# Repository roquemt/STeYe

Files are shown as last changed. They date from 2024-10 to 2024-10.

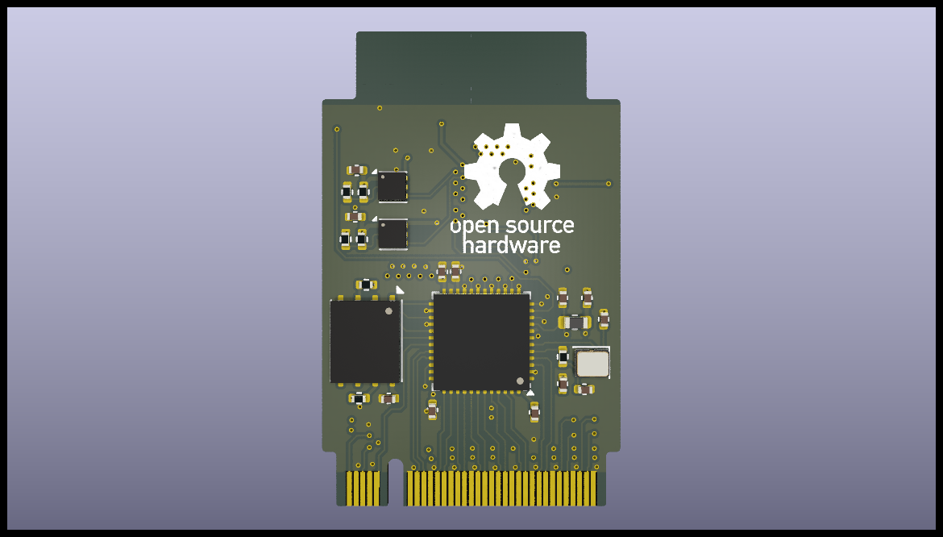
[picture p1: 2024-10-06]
STeYe M.2 Board/Renders/Bottom view.png

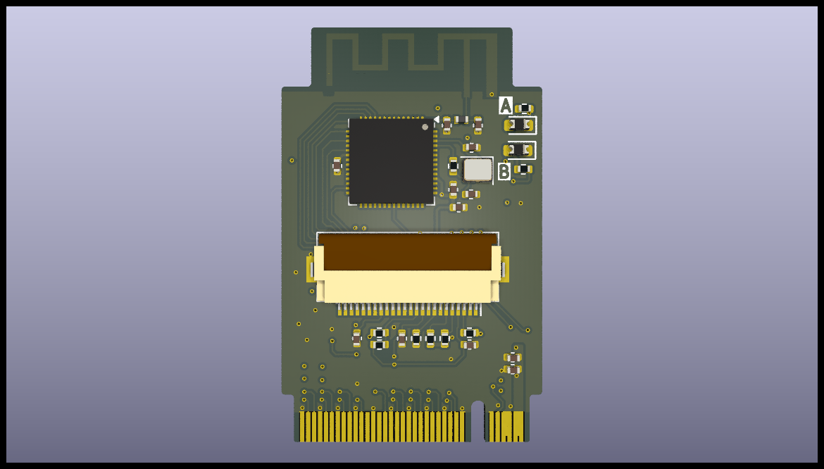
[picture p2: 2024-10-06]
STeYe M.2 Board/Renders/Top View.png

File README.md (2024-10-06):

# STeYe
Flight computer for rocket competition. 

This flight computer is designed for high-performance rocketry competitions, offering precise measurement and control for various flight parameters. The system integrates a range of sensors and features to ensure reliable data acquisition and communication throughout the flight. It is built with flexibility, durability, and scalability in mind for a variety of mission profiles.

Key Features:

-  Accelerometers: Dual-range accelerometers (+/-16g and +/-200g) for accurate low and high-g-force measurement during flight.
-  Pressure Sensor: Atmospheric pressure monitoring for altitude and environmental data.
-  Humidity & Temperature Sensor: Measures environmental conditions critical for flight analysis.
-  Magnetometer: Provides orientation and heading information by sensing the Earth’s magnetic field.
-  Current Sensor: Tracks power consumption for optimized energy management.
-  Camera Interface (FPC): Supports OV5640 camera for video and image capture during flight.
-  WiFi & Bluetooth: Wireless communication for data transfer and real-time telemetry.
-  GNSS (Global Navigation Satellite System): Provides accurate positioning data for tracking and flight path monitoring.
-  LoRa: Long-range, low-power communication capability for telemetry.
-  Pyro Channel: Single pyro channel for controlled deployment of parachutes or other pyrotechnic devices.
-  Motor Control: Supports either one dual-coil stepper motor or up to four servomotors, operating between 5V and 12V for mechanical actuation.
-  Passive Buzzer: Provides audio alerts for critical status or events.
-  LED Indicators: Visual feedback for power, status, and activity.
-  Memory: Includes both flash storage and microSD for data logging and flight data retention.

Carrier Board (sensors and peripherals)
Top view
Bottom view

M.2 Board (Microcontrollers and Wifi)
Top View
Bottom view

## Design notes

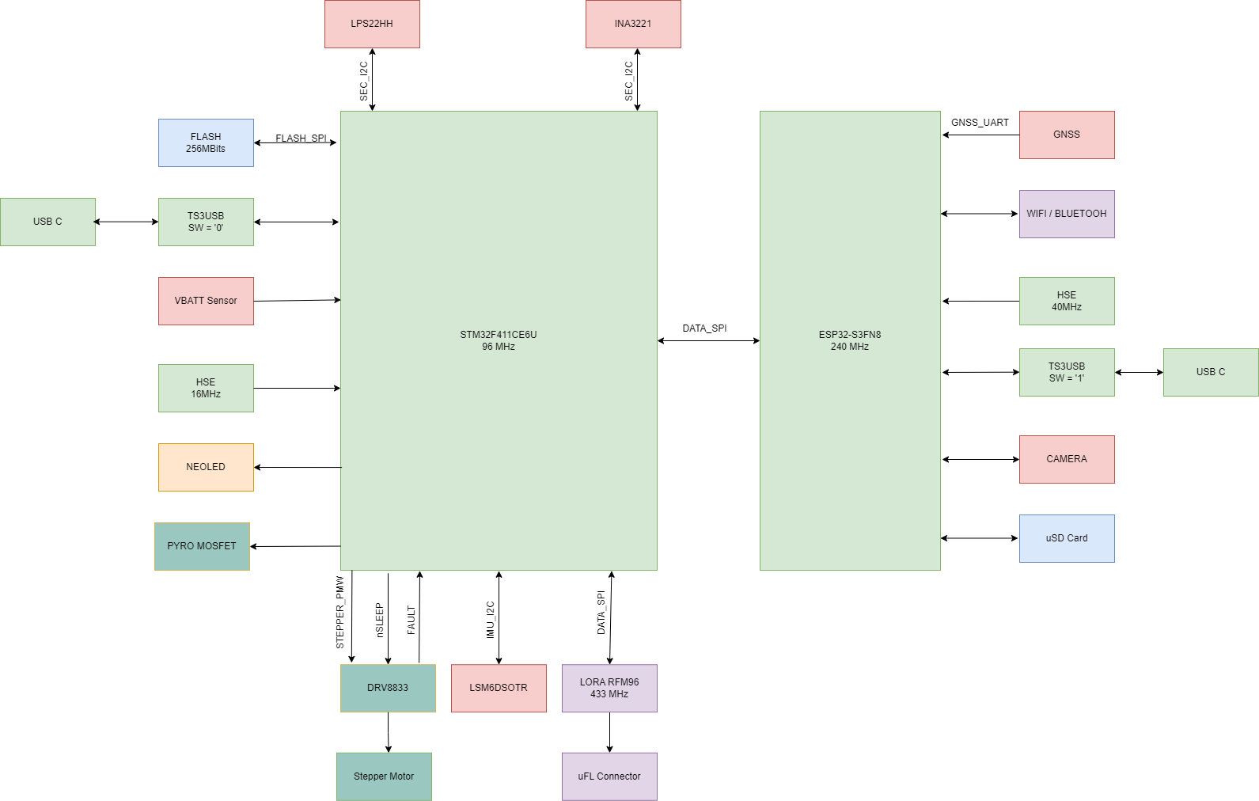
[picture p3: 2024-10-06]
Block Diagram.png

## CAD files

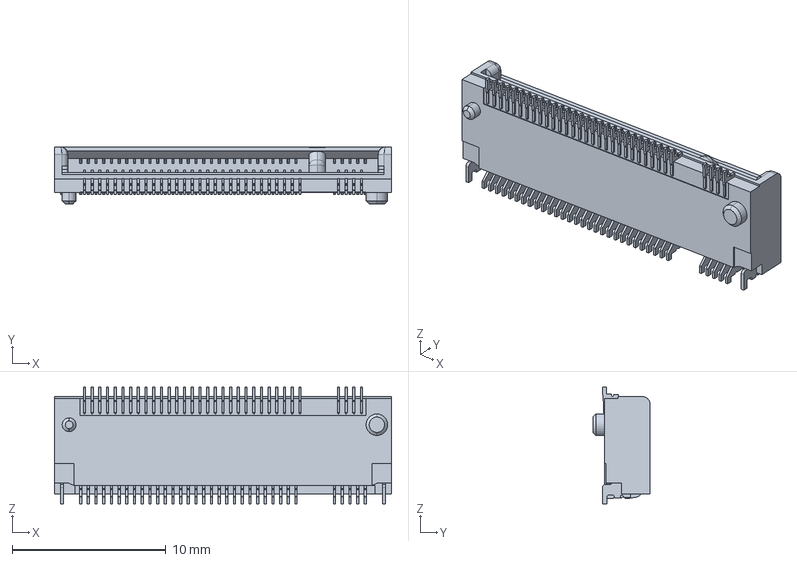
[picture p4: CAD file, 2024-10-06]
SteYe Carrier Board/3D models/sm3zs067u310amr1200.stp
21.9 x 3.72 x 7.60 mm

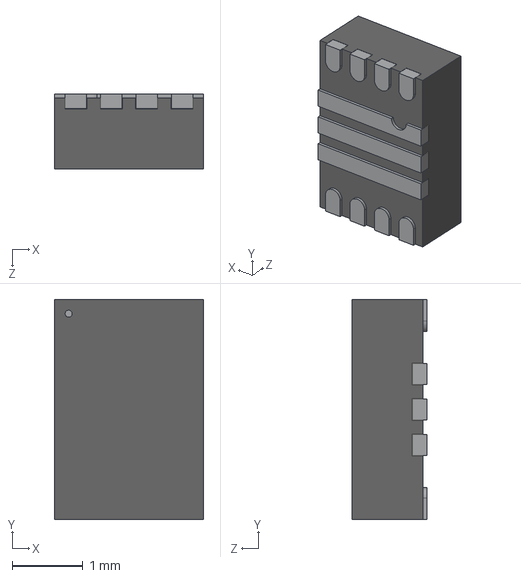
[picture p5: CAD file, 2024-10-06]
SteYe Carrier Board/3D models/User Library-Tps 62135.STEP
2.10 x 3.10 x 1.05 mm

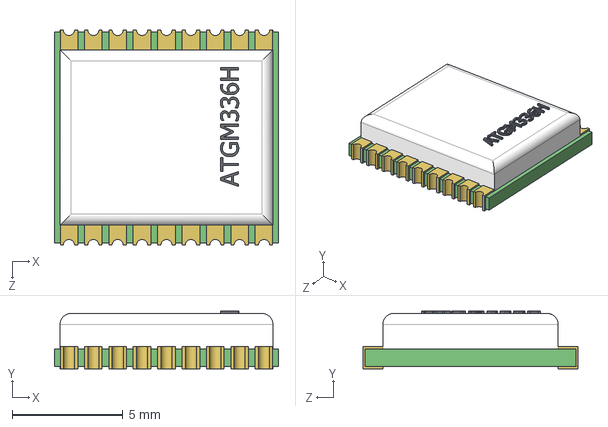
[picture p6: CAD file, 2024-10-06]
SteYe Carrier Board/3D models/User Library-ATGM336H.STEP
10.1 x 2.60 x 9.70 mm

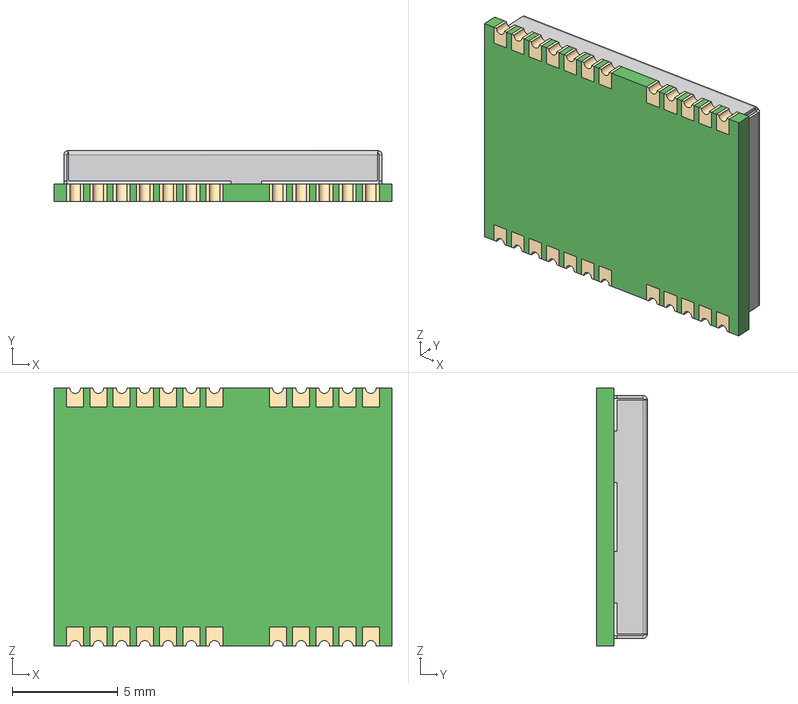
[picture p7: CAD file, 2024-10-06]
SteYe Carrier Board/3D models/U Blok NEO-6M-0-001.step
16.0 x 2.40 x 12.2 mm

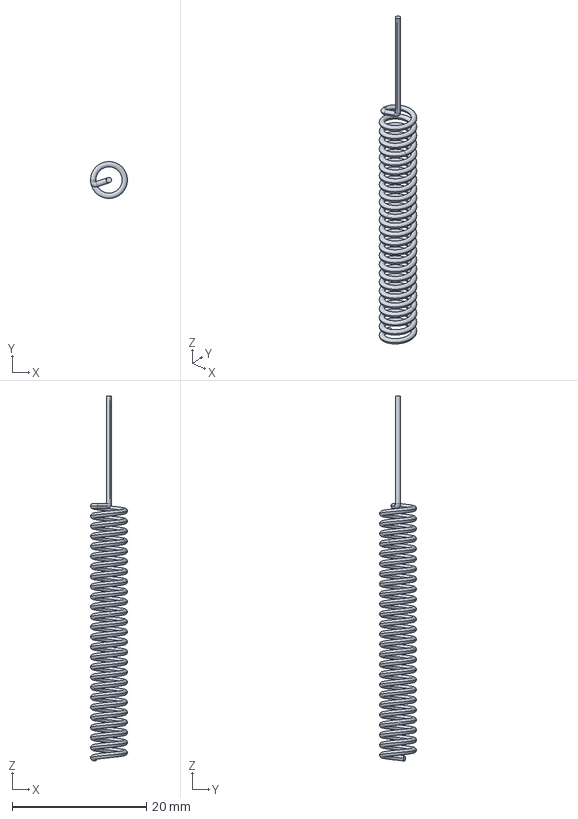
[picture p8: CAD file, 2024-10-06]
SteYe Carrier Board/3D models/433mhz_antenna_straight.stp
5.50 x 5.50 x 54.4 mm

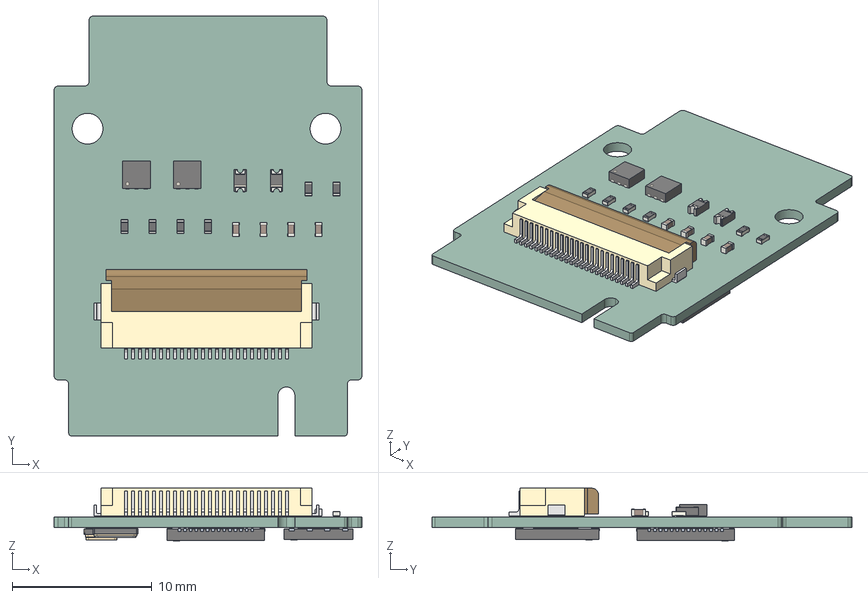
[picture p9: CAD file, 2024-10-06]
SteYe Carrier Board/3D models/STeYe_M2.step
22.0 x 30.0 x 3.76 mm
WSON_6_1EP_2x2mm_P065mm_EP1x16mm x 2
R_0402_1005Metric x 6
C_0402_1005Metric x 4
D_0603 x 2
Hirose_FH12_xxS_0_5SH_Parametric_v0_1
Crystal_SMD_3225-4Pin_3.2x2.5mm
Crystal_SMD_2520-4Pin_2.5x2.0mm
CQ assembly x 2
STeYe_M2_PCB

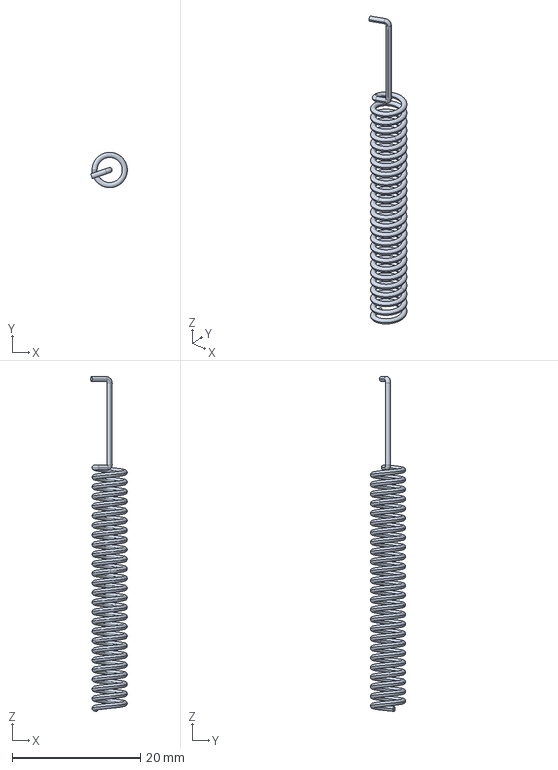
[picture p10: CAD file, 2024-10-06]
SteYe Carrier Board/3D models/433mhz_antenna_bended.stp
5.72 x 5.50 x 52.2 mm

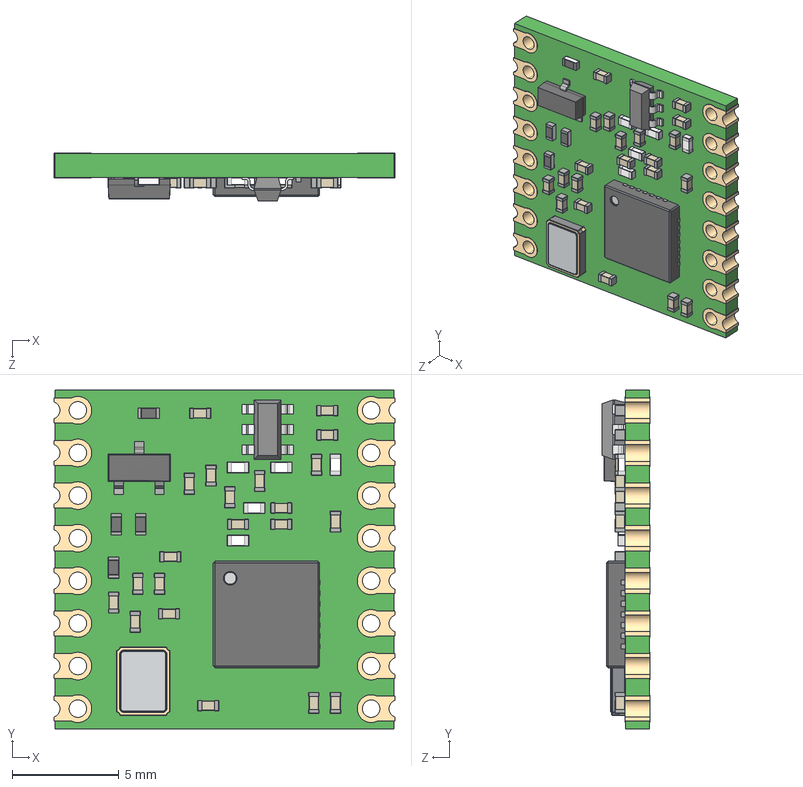
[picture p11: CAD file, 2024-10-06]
SteYe Carrier Board/3D models/User Library-RFM96W.STEP
16.0 x 15.9 x 2.23 mm
Board
Cap0402 x 21
SW3dPS-inductor_0402_white x 5
SW3dPS-SOT-23-6
QFN28
TXC_7M
Res0402 x 4
User_Library-3-lead_sot23-3
Goldcontact x 16

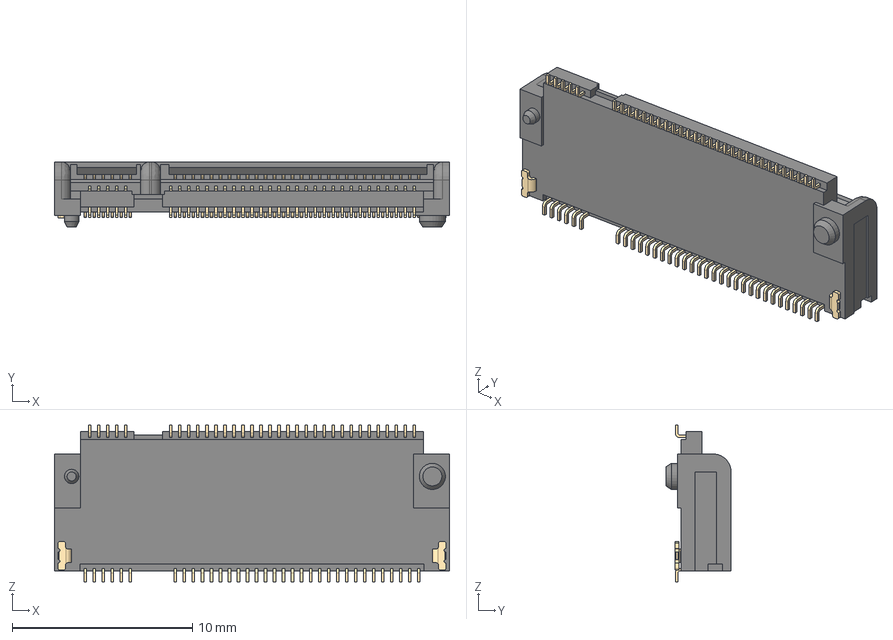
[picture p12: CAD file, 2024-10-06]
SteYe Carrier Board/3D models/2199119-5.step
21.9 x 3.62 x 8.70 mm

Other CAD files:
SteYe Carrier Board/3D models/433mhz_antenna_bended.igs
SteYe Carrier Board/3D models/433mhz_antenna_straight.igs

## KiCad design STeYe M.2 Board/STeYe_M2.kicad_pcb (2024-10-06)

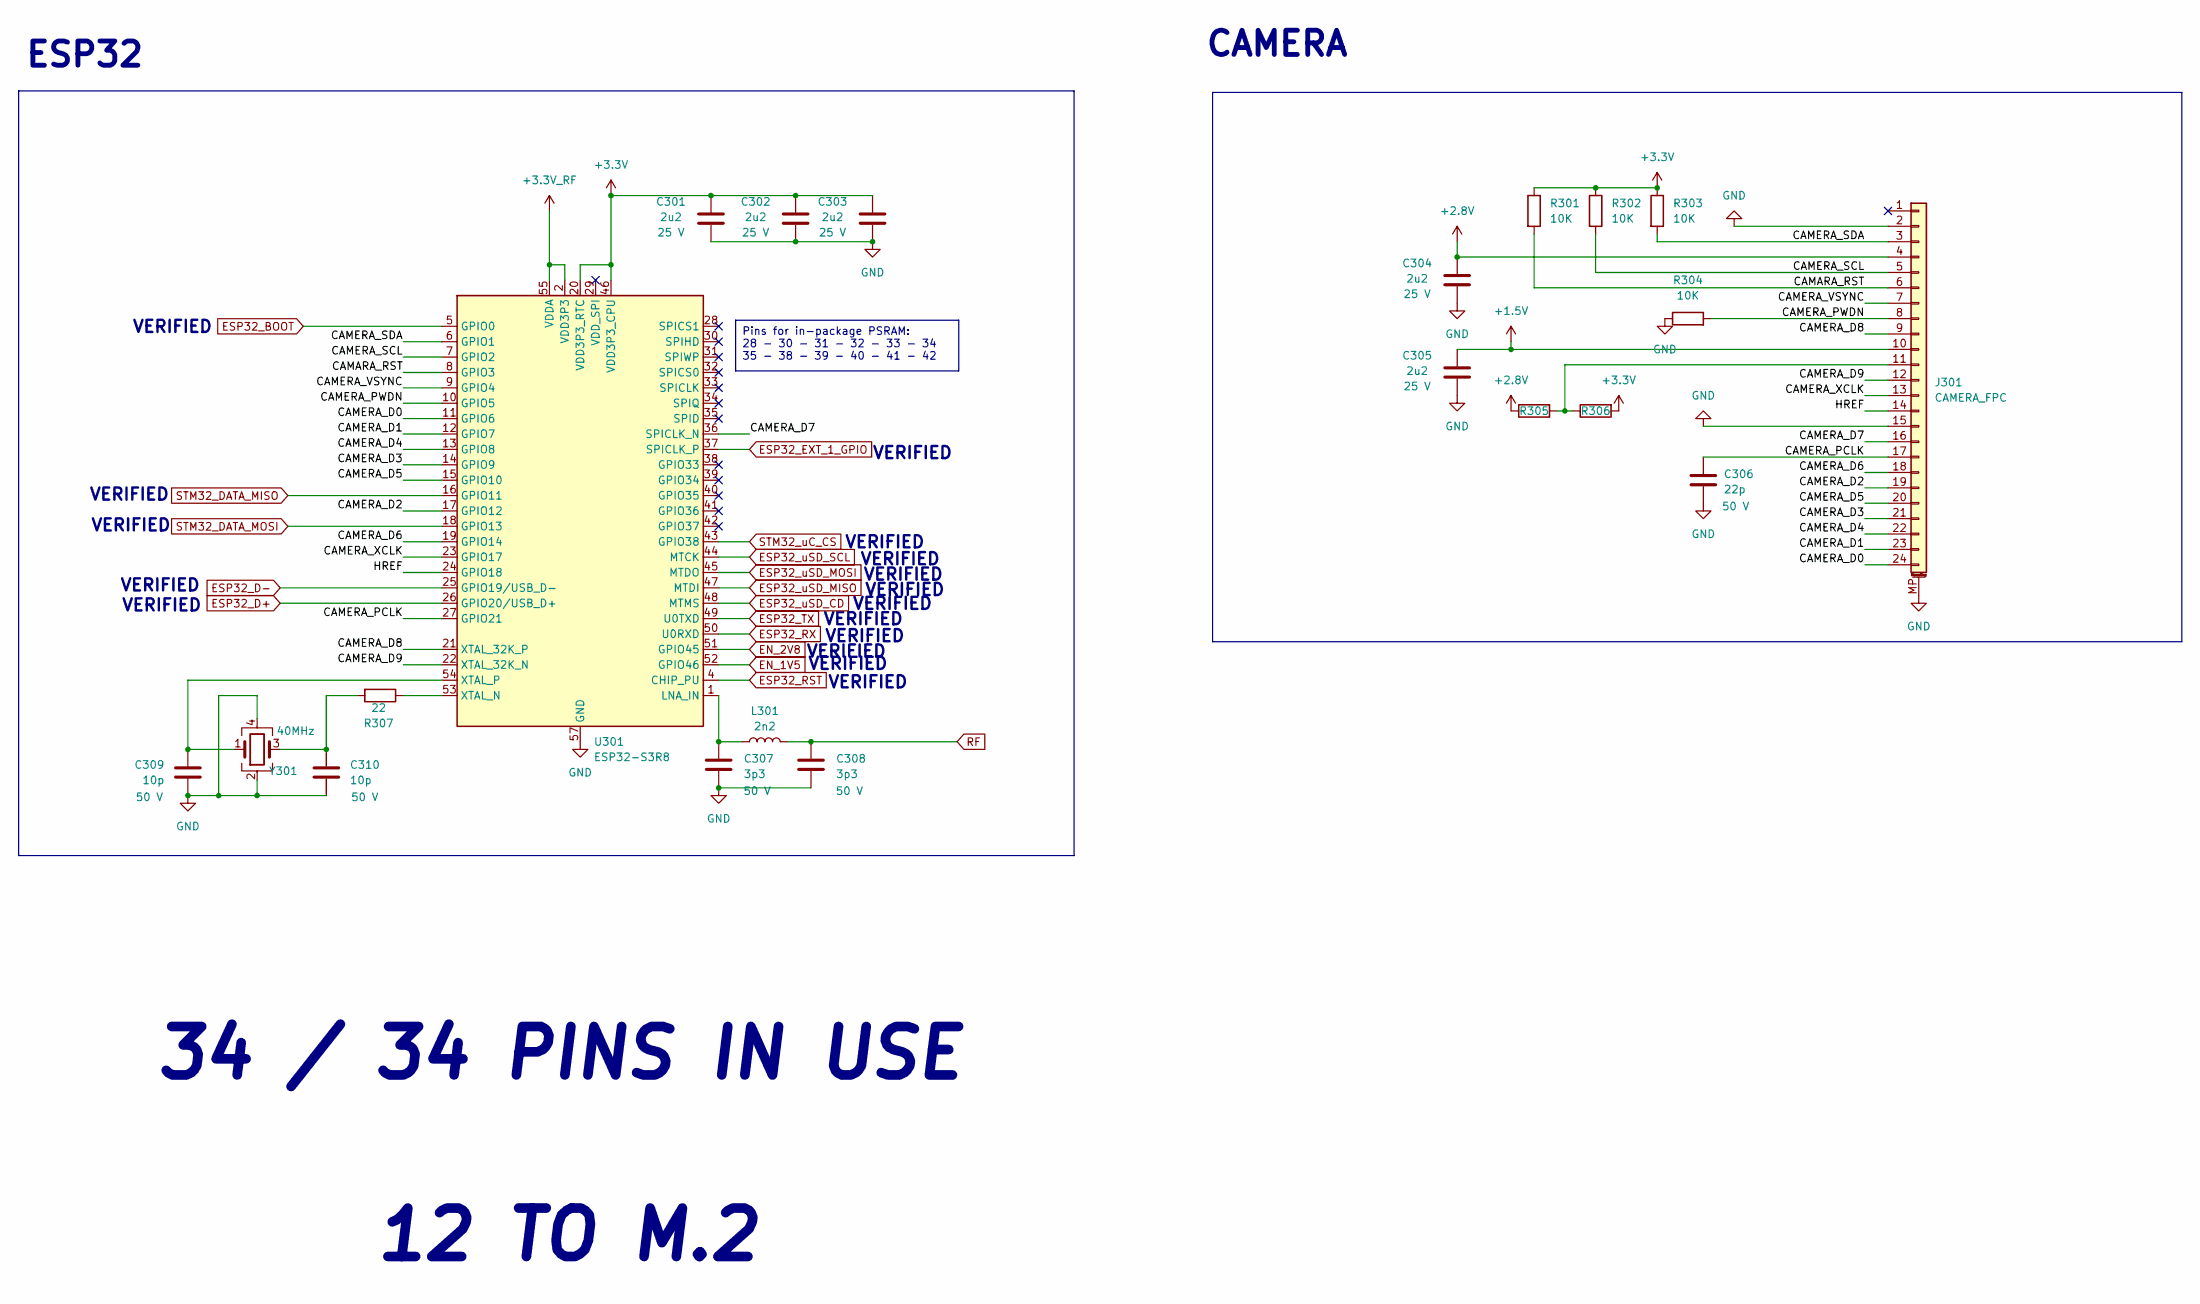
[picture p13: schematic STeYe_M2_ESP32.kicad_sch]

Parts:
C301, C302, C303, C304, C305: 2u2; C_0402_1005Metric; Voltage 25 V
C306: 22p; C_0402_1005Metric; Voltage 50 V
C307, C308: 3p3; C_0402_1005Metric; Voltage 50 V
C309, C310: 10p; C_0402_1005Metric; Voltage 50 V
J301: CAMERA_FPC; Hirose_FH12-24S-0.5SH_1x24-1MP_P0.50mm_Horizontal
L301: 2n2; Inductor
R301, R302, R303, R304: 10K; R_0402_1005Metric
R305, R306: R_0402_1005Metric
R307: 22; R_0402_1005Metric
U301: ESP32-S3R8; QFN-56-1EP_7x7mm_P0.4mm_EP4x4mm
Y301: 40MHz; Crystal_SMD_2016-4Pin_2.0x1.6mm

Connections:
+1.5V: C305.2, J301.10; also elsewhere on the board
+2.8V: C304.2, J301.4, R305.1; also elsewhere on the board
+3.3V: C301.2, C302.2, C303.2, R301.1, R302.1, R303.1, R306.2, U301.20 (VDD3P3_RTC), U301.46 (VDD3P3_CPU); also elsewhere on the board
+3.3V_RF: U301.2 (VDD3P3), U301.3 (VDD3P3), U301.55 (VDDA), U301.56 (VDDA); also elsewhere on the board
/ESP32/CAMARA_RST: J301.6, R301.2, U301.8 (GPIO3)
/ESP32/CAMERA_D0: J301.24, U301.11 (GPIO6)
/ESP32/CAMERA_D1: J301.23, U301.12 (GPIO7)
/ESP32/CAMERA_D2: J301.19, U301.17 (GPIO12)
/ESP32/CAMERA_D3: J301.21, U301.14 (GPIO9)
/ESP32/CAMERA_D4: J301.22, U301.13 (GPIO8)
/ESP32/CAMERA_D5: J301.20, U301.15 (GPIO10)
/ESP32/CAMERA_D6: J301.18, U301.19 (GPIO14)
/ESP32/CAMERA_D7: J301.16, U301.36 (SPICLK_N)
/ESP32/CAMERA_D8: J301.9, U301.21 (XTAL_32K_P)
/ESP32/CAMERA_D9: J301.12, U301.22 (XTAL_32K_N)
/ESP32/CAMERA_PCLK: C306.2, J301.17, U301.27 (GPIO21)
/ESP32/CAMERA_PWDN: J301.8, R304.2, U301.10 (GPIO5)
/ESP32/CAMERA_SCL: J301.5, R302.2, U301.7 (GPIO2)
/ESP32/CAMERA_SDA: J301.3, R303.2, U301.6 (GPIO1)
/ESP32/CAMERA_VSYNC: J301.7, U301.9 (GPIO4)
/ESP32/CAMERA_XCLK: J301.13, U301.23 (GPIO17)
/ESP32/HREF: J301.14, U301.24 (GPIO18)
EN_1V5: U301.52 (GPIO46); also elsewhere on the board
EN_2V8: U301.51 (GPIO45); also elsewhere on the board
ESP32_BOOT: U301.5 (GPIO0); also elsewhere on the board
ESP32_D+: U301.26 (GPIO20/USB_D+); also elsewhere on the board
ESP32_D-: U301.25 (GPIO19/USB_D-); also elsewhere on the board
ESP32_EXT_1_GPIO: U301.37 (SPICLK_P); also elsewhere on the board
ESP32_RST: U301.4 (CHIP_PU); also elsewhere on the board
ESP32_RX: U301.50 (U0RXD); also elsewhere on the board
ESP32_TX: U301.49 (U0TXD); also elsewhere on the board
ESP32_uSD_CD: U301.48 (MTMS); also elsewhere on the board
ESP32_uSD_MISO: U301.47 (MTDI); also elsewhere on the board
ESP32_uSD_MOSI: U301.45 (MTDO); also elsewhere on the board
ESP32_uSD_SCL: U301.44 (MTCK); also elsewhere on the board
GND: C301.1, C302.1, C303.1, C304.1, C305.1, C306.1, C307.2, C308.2, C309.2, C310.2, J301.2, J301.15, J301.MP (MountPin), R304.1, U301.57 (GND), Y301.2, Y301.4; also elsewhere on the board
unnamed: C310.1, R307.2, Y301.3
unnamed: J301.11, R305.2, R306.1
unnamed: C307.1, L301.1, U301.1 (LNA_IN)
unnamed: R307.1, U301.53 (XTAL_N)
unnamed: C309.1, U301.54 (XTAL_P), Y301.1
RF: C308.1, L301.2; also elsewhere on the board
STM32_DATA_MISO: U301.16 (GPIO11); also elsewhere on the board
STM32_DATA_MOSI: U301.18 (GPIO13); also elsewhere on the board
STM32_uC_CS: U301.43 (GPIO38); also elsewhere on the board

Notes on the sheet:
Pins for in-package PSRAM: 28 - 30 - 31 - 32 - 33 - 34 35 - 38 - 39 - 40 - 41 - 42
ESP32
VERIFIED
12 TO M.2
CAMERA
34 / 34 PINS IN USE

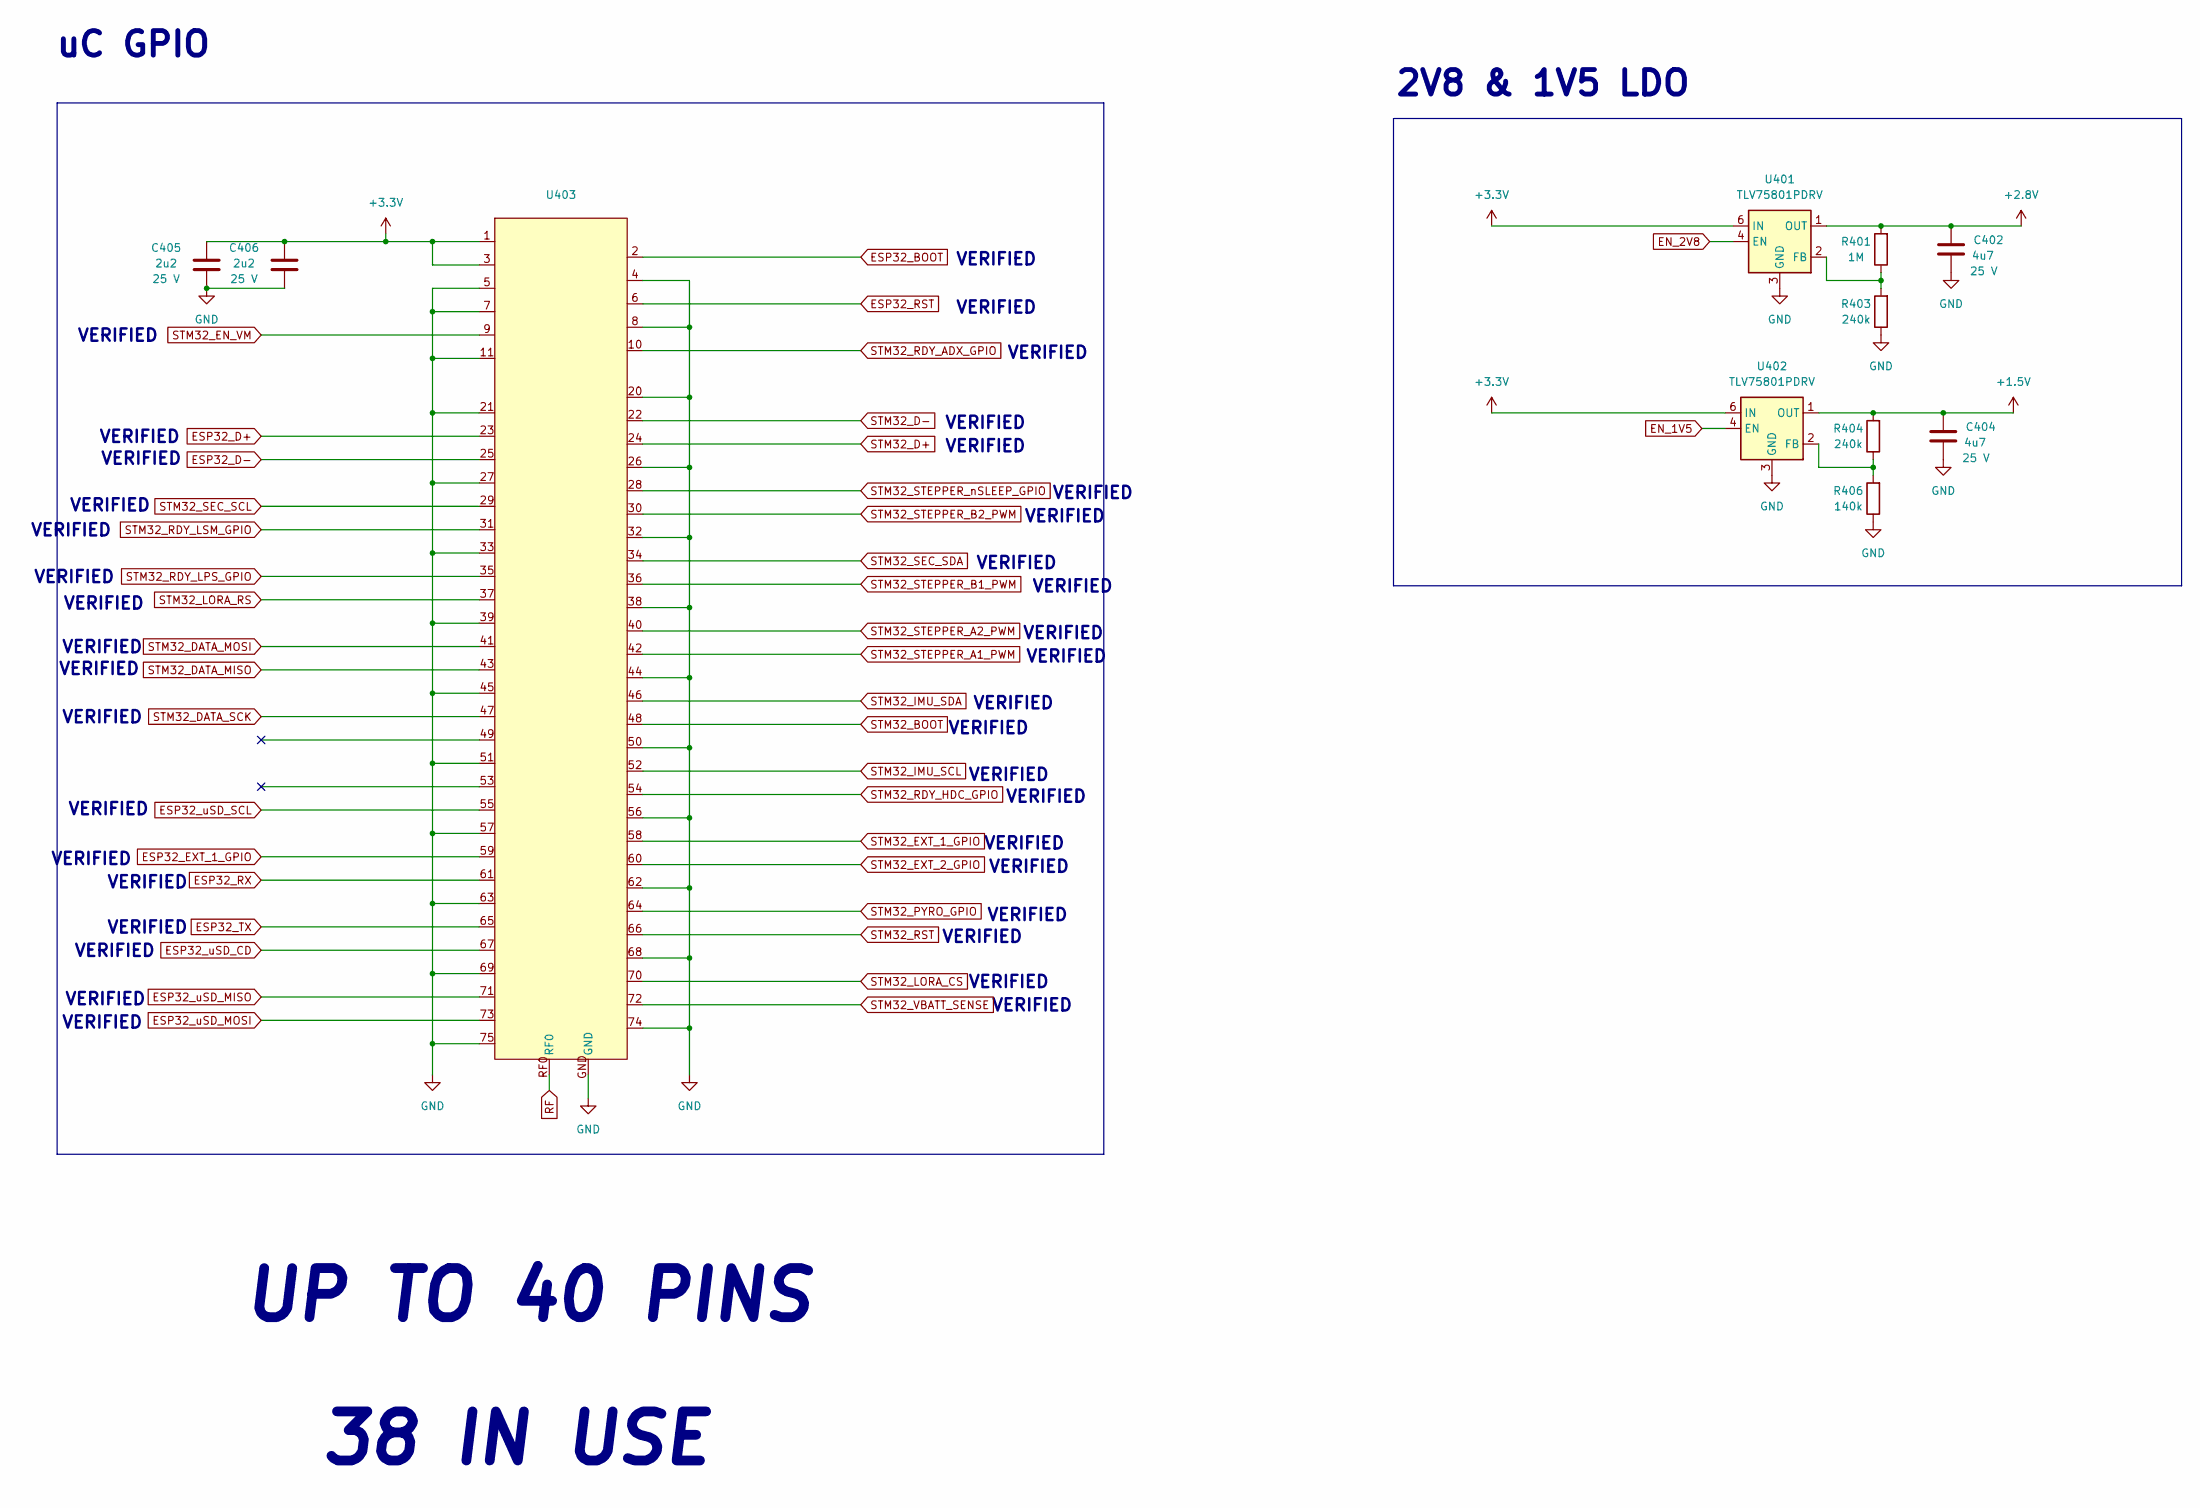
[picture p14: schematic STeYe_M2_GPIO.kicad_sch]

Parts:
C402, C404: 4u7; C_0402_1005Metric; Voltage 25 V
C405, C406: 2u2; C_0402_1005Metric; Voltage 25 V
R401: 1M; R_0402_1005Metric
R403, R404: 240k; R_0402_1005Metric
R406: 140k; R_0402_1005Metric
U401, U402: TLV75801PDRV; WSON-6-1EP_2x2mm_P0.65mm_EP1x1.6mm
U403: M.2-B-KEY_Antenna_1

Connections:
+1.5V: C404.1, R404.2, U402.1 (OUT); also elsewhere on the board
+2.8V: C402.1, R401.2, U401.1 (OUT); also elsewhere on the board
+3.3V: C405.2, C406.2, U401.6 (IN), U402.6 (IN), U403.1, U403.3; also elsewhere on the board
EN_1V5: U402.4 (EN); also elsewhere on the board
EN_2V8: U401.4 (EN); also elsewhere on the board
ESP32_BOOT: U403.2; also elsewhere on the board
ESP32_D+: U403.23; also elsewhere on the board
ESP32_D-: U403.25; also elsewhere on the board
ESP32_EXT_1_GPIO: U403.59; also elsewhere on the board
ESP32_RST: U403.6; also elsewhere on the board
ESP32_RX: U403.61; also elsewhere on the board
ESP32_TX: U403.65; also elsewhere on the board
ESP32_uSD_CD: U403.67; also elsewhere on the board
ESP32_uSD_MISO: U403.71; also elsewhere on the board
ESP32_uSD_MOSI: U403.73; also elsewhere on the board
ESP32_uSD_SCL: U403.55; also elsewhere on the board
GND: C402.2, C404.2, C405.1, C406.1, R403.1, R406.1, U401.3 (GND), U401.7 (GND), U402.3 (GND), U402.7 (GND), U403.4, U403.5, U403.7, U403.8, U403.11, U403.20, U403.21, U403.26, U403.27, U403.32, U403.33, U403.38, U403.39, U403.44, U403.45, U403.50, U403.51, U403.56, U403.57, U403.62, U403.63, U403.68, U403.69, U403.74, U403.75, U403.GND; also elsewhere on the board
unnamed: R401.1, R403.2, U401.2 (FB)
unnamed: R404.1, R406.2, U402.2 (FB)
RF: U403.RF0; also elsewhere on the board
STM32_BOOT: U403.48; also elsewhere on the board
STM32_D+: U403.24; also elsewhere on the board
STM32_D-: U403.22; also elsewhere on the board
STM32_DATA_MISO: U403.43; also elsewhere on the board
STM32_DATA_MOSI: U403.41; also elsewhere on the board
STM32_DATA_SCK: U403.47; also elsewhere on the board
STM32_EN_VM: U403.9; also elsewhere on the board
STM32_EXT_1_GPIO: U403.58; also elsewhere on the board
STM32_EXT_2_GPIO: U403.60; also elsewhere on the board
STM32_IMU_SCL: U403.52; also elsewhere on the board
STM32_IMU_SDA: U403.46; also elsewhere on the board
STM32_LORA_CS: U403.70; also elsewhere on the board
STM32_LORA_RS: U403.37; also elsewhere on the board
STM32_PYRO_GPIO: U403.64; also elsewhere on the board
STM32_RDY_ADX_GPIO: U403.10; also elsewhere on the board
STM32_RDY_HDC_GPIO: U403.54; also elsewhere on the board
STM32_RDY_LPS_GPIO: U403.35; also elsewhere on the board
STM32_RDY_LSM_GPIO: U403.31; also elsewhere on the board
STM32_RST: U403.66; also elsewhere on the board
STM32_SEC_SCL: U403.29; also elsewhere on the board
STM32_SEC_SDA: U403.34; also elsewhere on the board
STM32_STEPPER_A1_PWM: U403.42; also elsewhere on the board
STM32_STEPPER_A2_PWM: U403.40; also elsewhere on the board
STM32_STEPPER_B1_PWM: U403.36; also elsewhere on the board
STM32_STEPPER_B2_PWM: U403.30; also elsewhere on the board
STM32_STEPPER_nSLEEP_GPIO: U403.28; also elsewhere on the board
STM32_VBATT_SENSE: U403.72; also elsewhere on the board

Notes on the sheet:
VERIFIED
UP TO 40 PINS
uC GPIO
2V8 & 1V5 LDO
38 IN USE

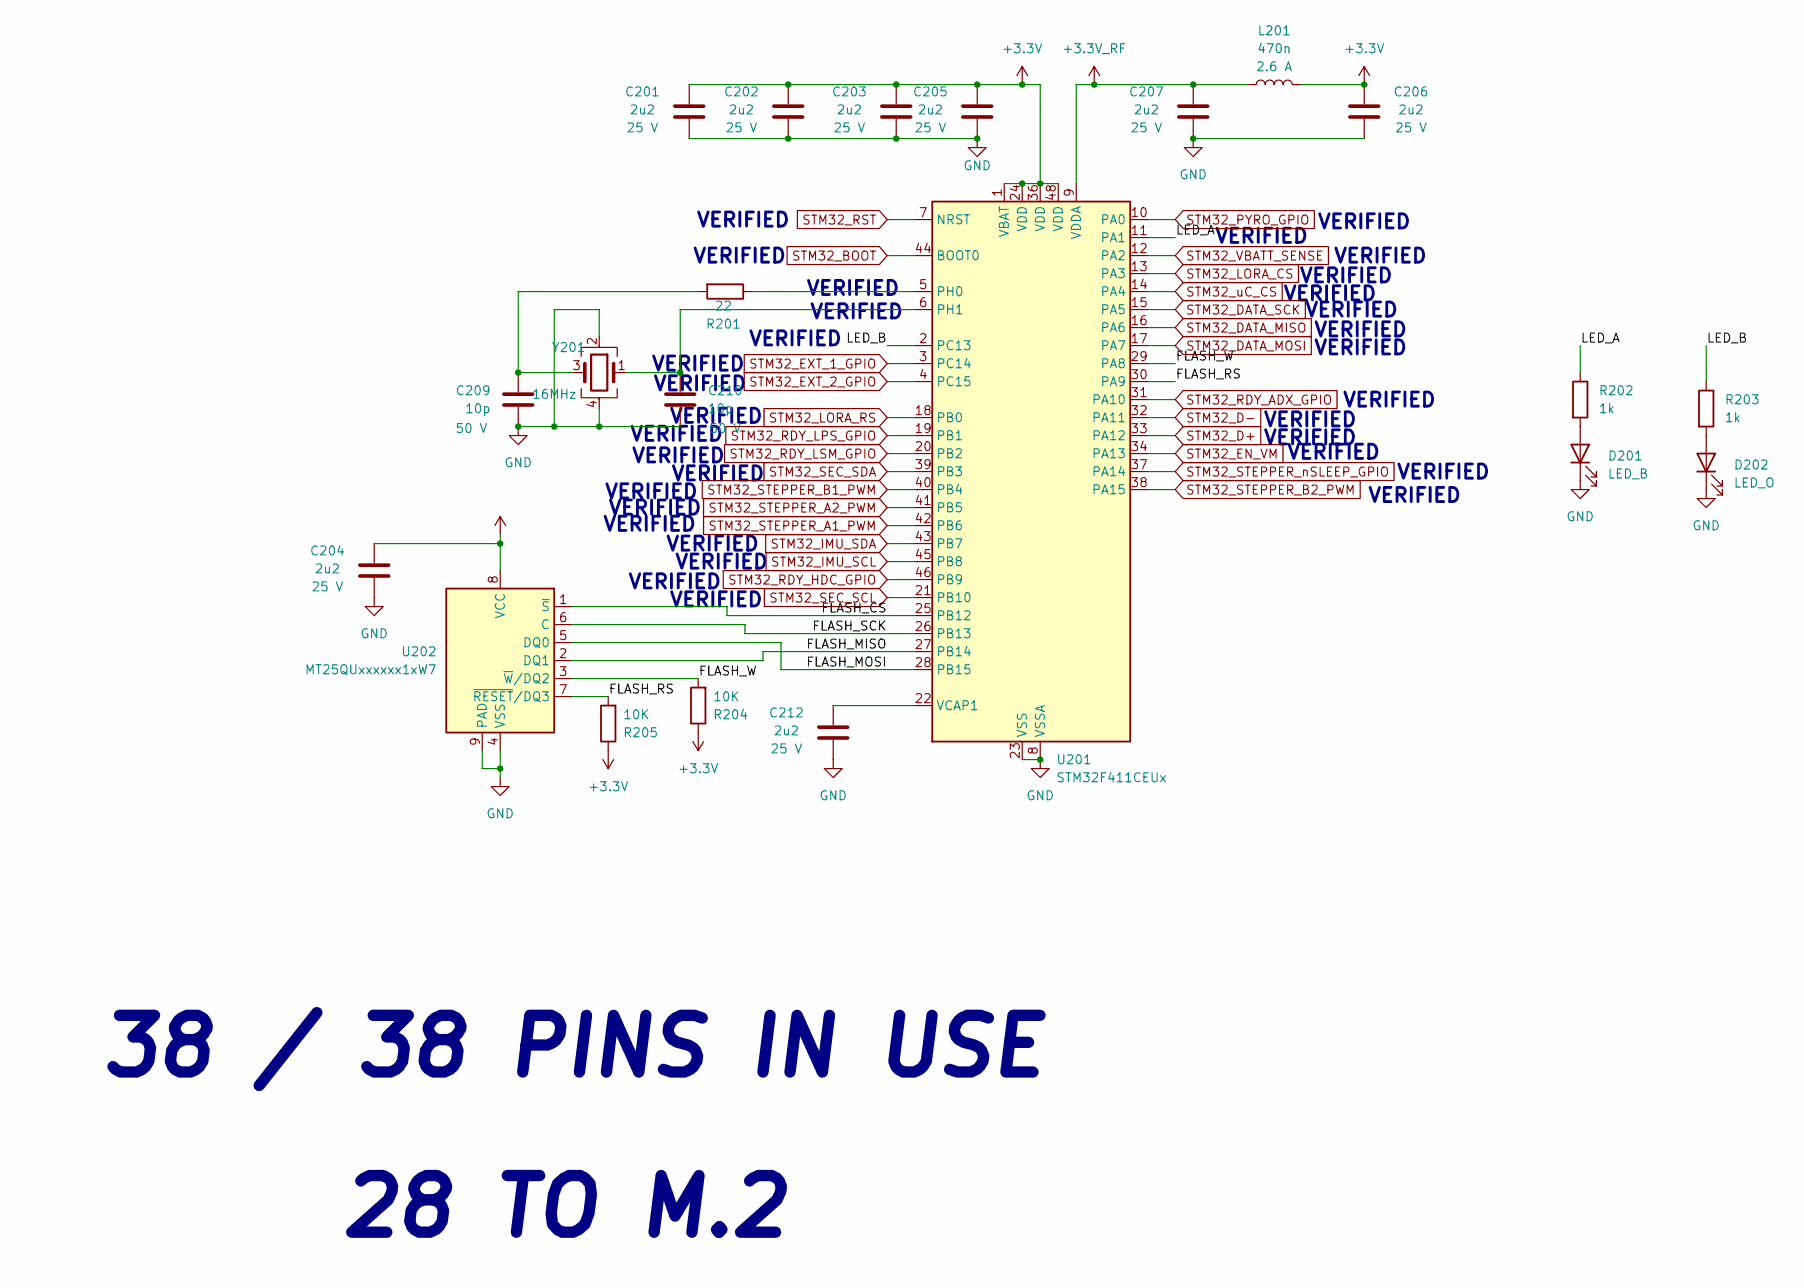
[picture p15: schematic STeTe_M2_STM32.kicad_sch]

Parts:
C201, C202, C203, C204, C205, C206, C207, C212: 2u2; C_0402_1005Metric; Voltage 25 V
C209, C210: 10p; C_0402_1005Metric; Voltage 50 V
D201: LED_B; D_0603_1608Metric
D202: LED_O; D_0603_1608Metric
L201: 470n; L_0603_1608Metric
R201: 22; R_0402_1005Metric
R202, R203: 1k; R_0402_1005Metric
R204, R205: 10K; R_0402_1005Metric
U201: STM32F411CEUx; QFN-48-1EP_7x7mm_P0.5mm_EP5.6x5.6mm
U202: MT25QUxxxxxx1xW7; W-PDFN-8-1EP_6x5mm_P1.27mm_EP3x3mm
Y201: 16MHz; Crystal_SMD_2016-4Pin_2.0x1.6mm

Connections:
+3.3V: C201.2, C202.2, C203.2, C204.2, C205.2, C206.2, L201.2, R204.1, R205.1, U201.1 (VBAT), U201.24 (VDD), U201.36 (VDD), U201.48 (VDD), U202.8 (VCC); also elsewhere on the board
+3.3V_RF: C207.2, L201.1, U201.9 (VDDA); also elsewhere on the board
/STM32/FLASH_CS: U201.25 (PB12), U202.1 (~S)
/STM32/FLASH_MISO: U201.27 (PB14), U202.2 (DQ1)
/STM32/FLASH_MOSI: U201.28 (PB15), U202.5 (DQ0)
/STM32/FLASH_RS: R205.2, U201.30 (PA9), U202.7 (~RESET/DQ3)
/STM32/FLASH_SCK: U201.26 (PB13), U202.6 (C)
/STM32/FLASH_W: R204.2, U201.29 (PA8), U202.3 (~W/DQ2)
/STM32/LED_A: R202.1, U201.11 (PA1)
/STM32/LED_B: R203.1, U201.2 (PC13)
GND: C201.1, C202.1, C203.1, C204.1, C205.1, C206.1, C207.1, C209.2, C210.2, C212.1, D201.1 (K), D202.1 (K), U201.8 (VSSA), U201.23 (VSS), U201.35 (VSS), U201.47 (VSS), U201.49 (VSS), U202.4 (VSS), U202.9 (PAD), Y201.2, Y201.4; also elsewhere on the board
unnamed: C209.1, R201.2, Y201.3
unnamed: D201.2 (A), R202.2
unnamed: D202.2 (A), R203.2
unnamed: R201.1, U201.5 (PH0)
unnamed: C210.1, U201.6 (PH1), Y201.1
unnamed: C212.2, U201.22 (VCAP1)
STM32_BOOT: U201.44 (BOOT0); also elsewhere on the board
STM32_D+: U201.33 (PA12); also elsewhere on the board
STM32_D-: U201.32 (PA11); also elsewhere on the board
STM32_DATA_MISO: U201.16 (PA6); also elsewhere on the board
STM32_DATA_MOSI: U201.17 (PA7); also elsewhere on the board
STM32_DATA_SCK: U201.15 (PA5); also elsewhere on the board
STM32_EN_VM: U201.34 (PA13); also elsewhere on the board
STM32_EXT_1_GPIO: U201.3 (PC14); also elsewhere on the board
STM32_EXT_2_GPIO: U201.4 (PC15); also elsewhere on the board
STM32_IMU_SCL: U201.45 (PB8); also elsewhere on the board
STM32_IMU_SDA: U201.43 (PB7); also elsewhere on the board
STM32_LORA_CS: U201.13 (PA3); also elsewhere on the board
STM32_LORA_RS: U201.18 (PB0); also elsewhere on the board
STM32_PYRO_GPIO: U201.10 (PA0); also elsewhere on the board
STM32_RDY_ADX_GPIO: U201.31 (PA10); also elsewhere on the board
STM32_RDY_HDC_GPIO: U201.46 (PB9); also elsewhere on the board
STM32_RDY_LPS_GPIO: U201.19 (PB1); also elsewhere on the board
STM32_RDY_LSM_GPIO: U201.20 (PB2); also elsewhere on the board
STM32_RST: U201.7 (NRST); also elsewhere on the board
STM32_SEC_SCL: U201.21 (PB10); also elsewhere on the board
STM32_SEC_SDA: U201.39 (PB3); also elsewhere on the board
STM32_STEPPER_A1_PWM: U201.42 (PB6); also elsewhere on the board
STM32_STEPPER_A2_PWM: U201.41 (PB5); also elsewhere on the board
STM32_STEPPER_B1_PWM: U201.40 (PB4); also elsewhere on the board
STM32_STEPPER_B2_PWM: U201.38 (PA15); also elsewhere on the board
STM32_STEPPER_nSLEEP_GPIO: U201.37 (PA14); also elsewhere on the board
STM32_VBATT_SENSE: U201.12 (PA2); also elsewhere on the board
STM32_uC_CS: U201.14 (PA4); also elsewhere on the board

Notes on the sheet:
VERIFIED
28 TO M.2
38 / 38 PINS IN USE

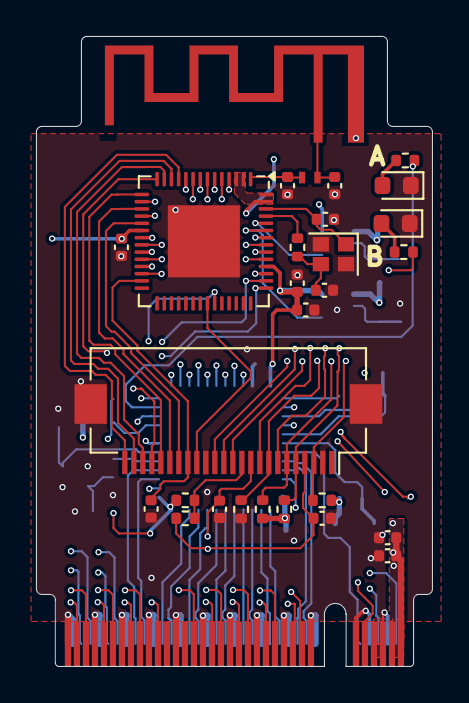
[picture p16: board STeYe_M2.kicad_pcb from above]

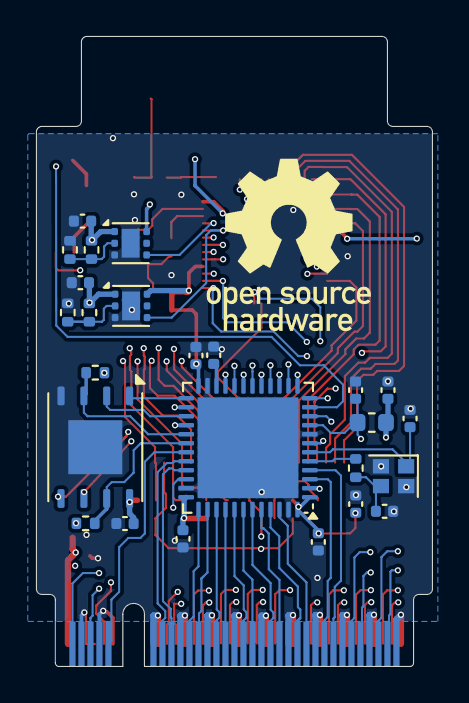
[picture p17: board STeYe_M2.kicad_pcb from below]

Board: 8 copper layers, 22.0 x 35.0 mm, 53 parts (25 on the bottom side), 86 nets.

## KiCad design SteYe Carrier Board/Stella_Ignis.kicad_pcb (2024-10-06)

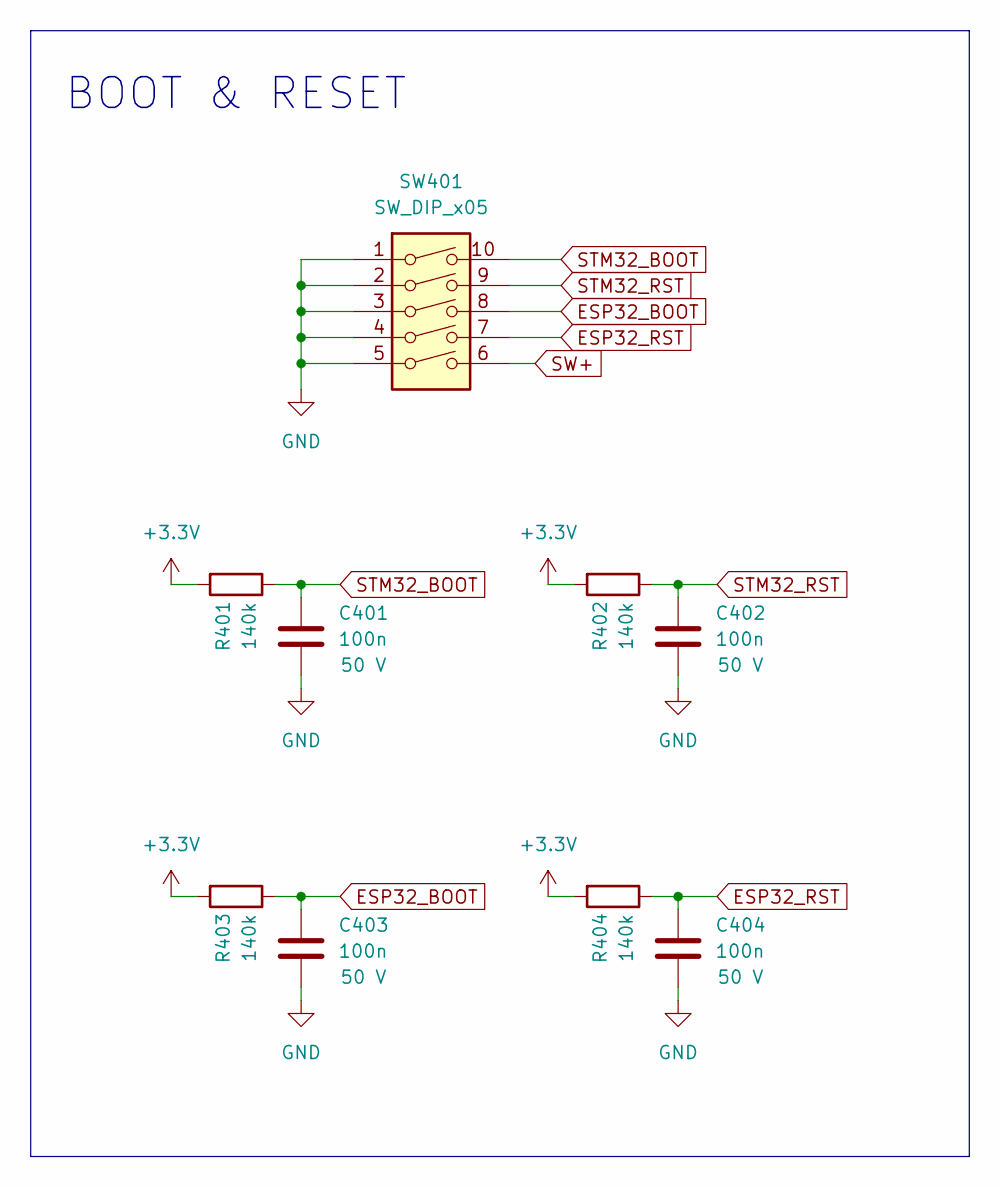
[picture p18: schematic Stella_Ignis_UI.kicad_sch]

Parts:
C401, C402, C403, C404: 100n; C_0402_1005Metric; Voltage 50 V
R401, R402, R403, R404: 140k; R_0402_1005Metric
SW401: SW_DIP_x05; SW_DIP_SPSTx05_Slide_6.7x14.26mm_W8.61mm_P2.54mm_LowProfile

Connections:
+3.3V: R401.2, R402.2, R403.2, R404.2; also elsewhere on the board
ESP32_BOOT: C403.1, R403.1, SW401.8; also elsewhere on the board
ESP32_RST: C404.1, R404.1, SW401.7; also elsewhere on the board
GND: C401.2, C402.2, C403.2, C404.2, SW401.1, SW401.2, SW401.3, SW401.4, SW401.5; also elsewhere on the board
STM32_BOOT: C401.1, R401.1, SW401.10; also elsewhere on the board
STM32_RST: C402.1, R402.1, SW401.9; also elsewhere on the board
SW+: SW401.6; also elsewhere on the board

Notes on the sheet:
BOOT & RESET

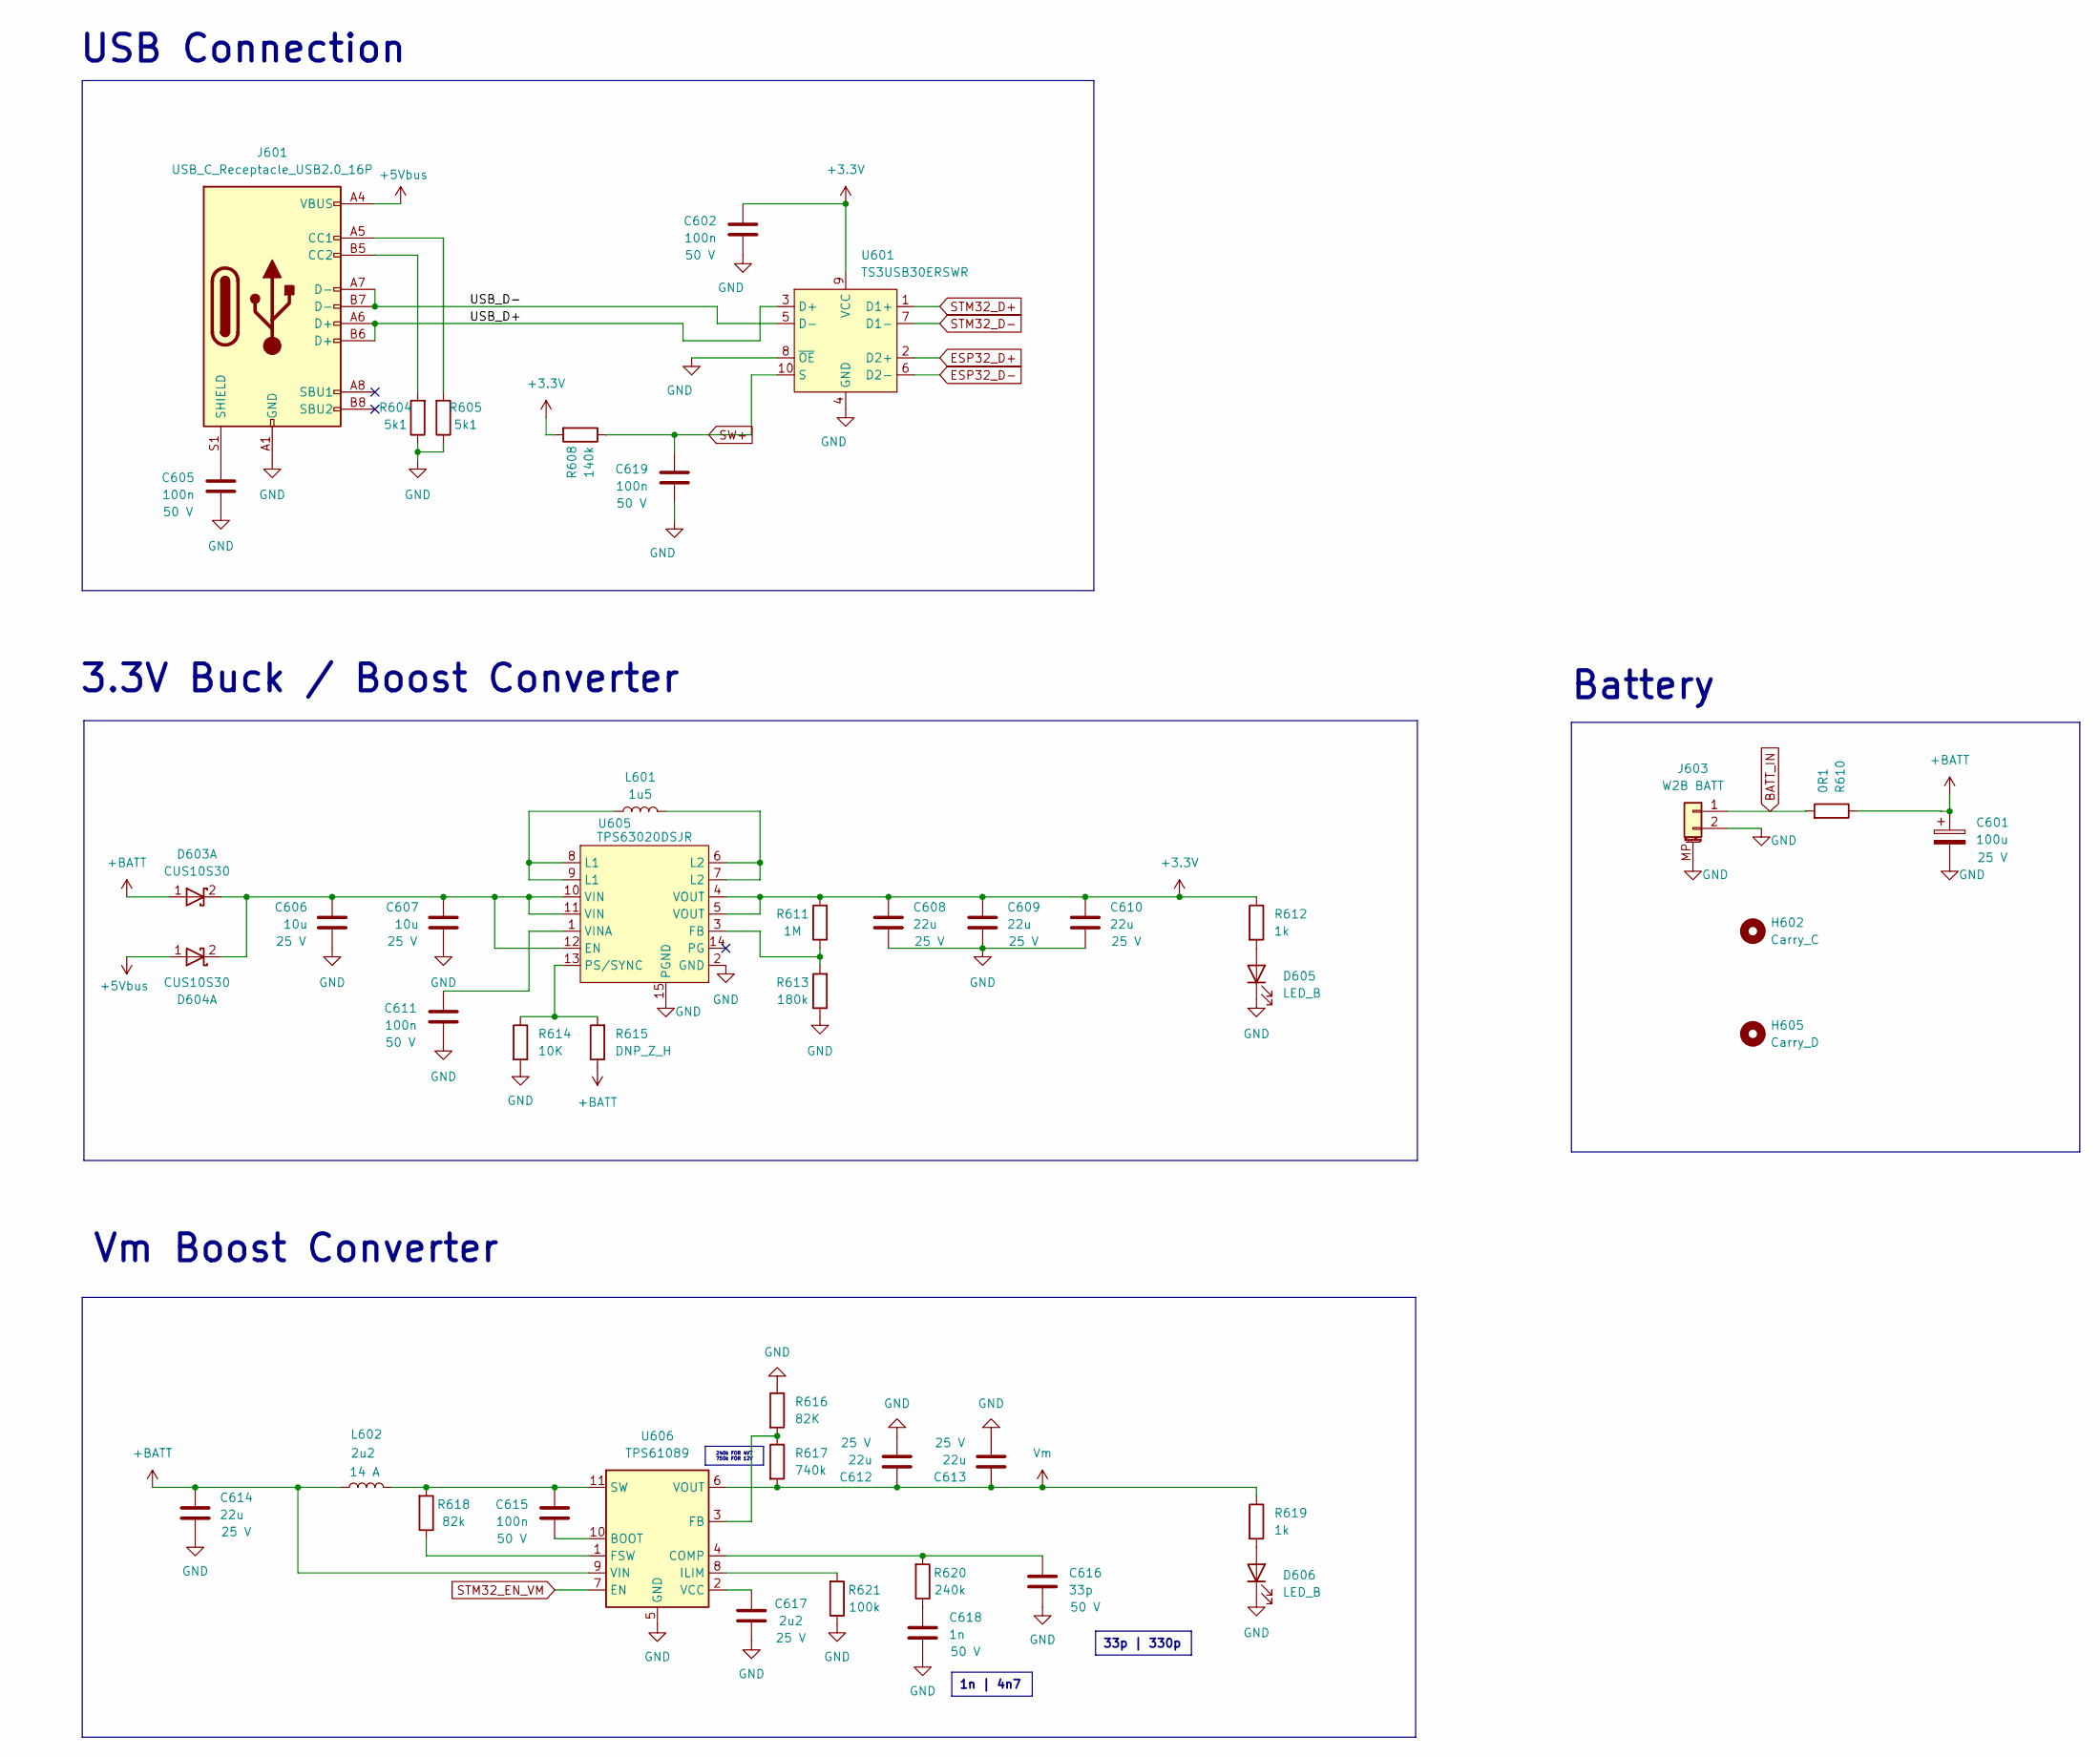
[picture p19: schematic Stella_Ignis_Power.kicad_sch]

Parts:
C601: 100u; CP_EIA-6032-15_Kemet-U_Pad2.25x2.35mm_HandSolder; Voltage 25 V
C602, C605, C611, C615, C619: 100n; C_0402_1005Metric; Voltage 50 V
C606, C607: 10u; C_0402_1005Metric; Voltage 25 V
C608, C609, C610, C612, C613, C614: 22u; C_0805_2012Metric; Voltage 25 V
C616: 33p; C_0402_1005Metric; Voltage 50 V
C617: 2u2; C_0402_1005Metric; Voltage 25 V
C618: 1n; C_0402_1005Metric; Voltage 50 V
D603, D604: CUS10S30; D_SOD-323
D605, D606: LED_B; D_0603_1608Metric
H602: Carry_C; MountingHole_2.2mm_M2
H605: Carry_D; MountingHole_2.2mm_M2
J601: USB_C_Receptacle_USB2.0_16P; USB_C_Receptacle_GCT_USB4105-xx-A_16P_TopMnt_Horizontal
J603: W2B BATT; Molex_PicoBlade_53261-0271_1x02-1MP_P1.25mm_Horizontal
L601: 1u5; Inductor SLO201610T1R5MTT
L602: 2u2; L_Sunlord_MWSA0605S
R604, R605: 5k1; R_0402_1005Metric
R608: 140k; R_0402_1005Metric
R610: 0R1; R_0805_2012Metric
R611: 1M; R_0402_1005Metric
R612, R619: 1k; R_0402_1005Metric
R613: 180k; R_0402_1005Metric
R614: 10K; R_0402_1005Metric
R615: DNP_Z_H; R_0402_1005Metric
R616: 82K; R_0402_1005Metric
R617: 740k; R_0402_1005Metric
R618: 82k; R_0402_1005Metric
R620: 240k; R_0402_1005Metric
R621: 100k; R_0402_1005Metric
U601: TS3USB30ERSWR; UQFN-10_1.4x1.8mm_P0.4mm
U605: TPS63020DSJR
U606: TPS61089; Texas_VQFN-RNR0011A-11

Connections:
+3.3V: C602.1, C608.1, C609.1, C610.1, R608.2, R611.2, R612.1, U601.9 (VCC), U605.4 (VOUT), U605.5 (VOUT); also elsewhere on the board
+5Vbus: D604.1 (A), J601.A4 (VBUS), J601.A9 (VBUS), J601.B4 (VBUS), J601.B9 (VBUS)
+BATT: C601.1, C614.1, D603.1 (A), L602.1, R610.1, R615.1, U606.9 (VIN); also elsewhere on the board
/Power Stage/USB_D+: J601.A6 (D+), J601.B6 (D+), U601.3 (D+)
/Power Stage/USB_D-: J601.A7 (D-), J601.B7 (D-), U601.5 (D-)
BATT_IN: J603.1, R610.2; also elsewhere on the board
ESP32_D+: U601.2 (D2+); also elsewhere on the board
ESP32_D-: U601.6 (D2-); also elsewhere on the board
GND: C601.2, C602.2, C605.2, C606.2, C607.2, C608.2, C609.2, C610.2, C611.2, C612.2, C613.2, C614.2, C616.2, C617.2, C618.2, C619.2, D605.1 (K), D606.1 (K), J601.A1 (GND), J601.A12 (GND), J601.B1 (GND), J601.B12 (GND), J603.2, J603.MP (MountPin), R604.1, R605.1, R613.1, R614.2, R616.1, R621.1, U601.4 (GND), U601.8 (~OE), U605.2 (GND), U605.15 (PGND), U606.5 (GND); also elsewhere on the board
unnamed: C618.1, R620.1
unnamed: C606.1, C607.1, D603.2 (K), D604.2 (K), U605.10 (VIN), U605.11 (VIN), U605.12 (EN)
unnamed: D605.2 (A), R612.2
unnamed: D606.2 (A), R619.2
unnamed: J601.A5 (CC1), R605.2
unnamed: J601.B5 (CC2), R604.2
unnamed: C605.1, J601.S1 (SHIELD)
unnamed: L601.1, U605.8 (L1), U605.9 (L1)
unnamed: L601.2, U605.6 (L2), U605.7 (L2)
unnamed: R611.1, R613.2, U605.3 (FB)
unnamed: R614.1, R615.2, U605.13 (PS/SYNC)
unnamed: C611.1, U605.1 (VINA)
unnamed: C615.2, U606.10 (BOOT)
unnamed: C616.1, R620.2, U606.4 (COMP)
unnamed: R616.2, R617.1, U606.3 (FB)
unnamed: R618.1, U606.1 (FSW)
unnamed: R621.2, U606.8 (ILIM)
unnamed: C615.1, L602.2, R618.2, U606.11 (SW)
unnamed: C617.1, U606.2 (VCC)
STM32_D+: U601.1 (D1+); also elsewhere on the board
STM32_D-: U601.7 (D1-); also elsewhere on the board
STM32_EN_VM: U606.7 (EN); also elsewhere on the board
SW+: C619.1, R608.1, U601.10 (S); also elsewhere on the board
Vm: C612.1, C613.1, R617.2, R619.1, U606.6 (VOUT); also elsewhere on the board

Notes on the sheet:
33p | 330p
240k FOR 4V7 750k FOR 12V
1n | 4n7
USB Connection
Vm Boost Converter
Battery
3.3V Buck / Boost Converter

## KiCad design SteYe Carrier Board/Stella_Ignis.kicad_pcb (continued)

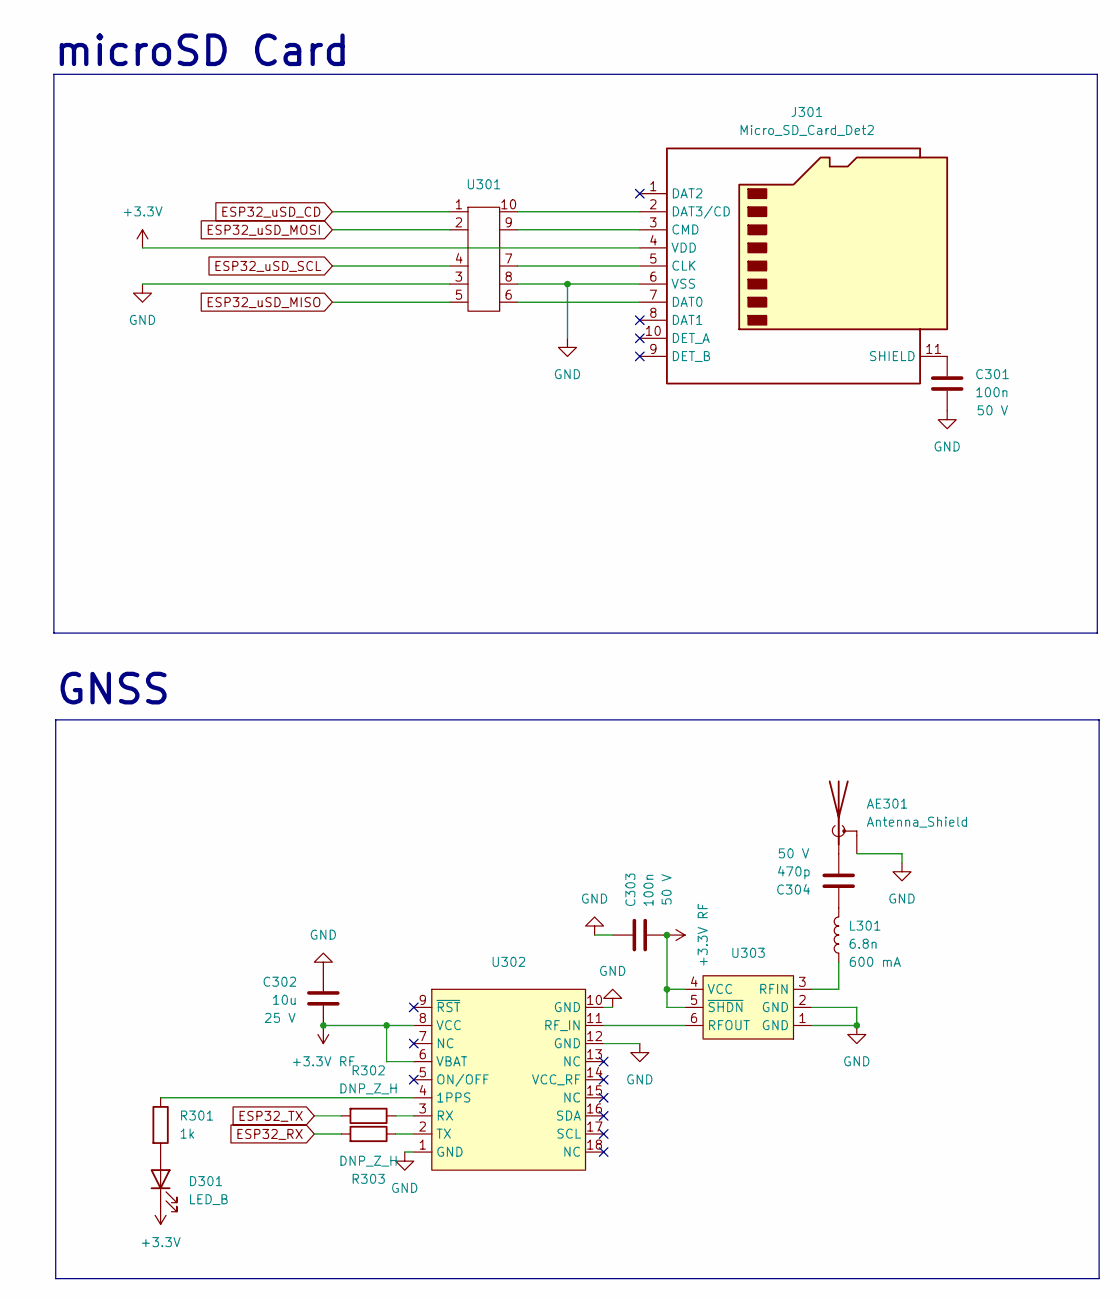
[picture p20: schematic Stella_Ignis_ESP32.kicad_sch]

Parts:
AE301: Antenna_Shield; U.FL_Hirose_U.FL-R-SMT-1_Vertical
C301, C303: 100n; C_0402_1005Metric; Voltage 50 V
C302: 10u; C_0402_1005Metric; Voltage 25 V
C304: 470p; C_0402_1005Metric; Voltage 50 V
D301: LED_B; D_0603_1608Metric
J301: Micro_SD_Card_Det2; microSD_HC_Hirose_DM3D-SF
L301: 6.8n; L_0402_1005Metric
R301: 1k; R_0402_1005Metric
R302, R303: DNP_Z_H; R_0402_1005Metric
U301: Diodes_UDFN-10_1.0x2.5mm_P0.5mm
U302: ATGM336H
U303: DFN-6-1EP_2x2mm_P0.5mm_EP0.61x1.42mm

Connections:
+3.3V: D301.1 (K), J301.4 (VDD); also elsewhere on the board
+3.3V RF: C302.2, C303.2, U302.6 (VBAT), U302.8 (VCC), U303.4 (VCC), U303.5 (~SHDN); also elsewhere on the board
ESP32_RX: R303.2; also elsewhere on the board
ESP32_TX: R302.2; also elsewhere on the board
ESP32_uSD_CD: U301.1; also elsewhere on the board
ESP32_uSD_MISO: U301.5; also elsewhere on the board
ESP32_uSD_MOSI: U301.2; also elsewhere on the board
ESP32_uSD_SCL: U301.4; also elsewhere on the board
GND: AE301.2 (Shield), C301.2, C302.1, C303.1, J301.6 (VSS), U301.3, U301.8, U302.1 (GND), U302.10 (GND), U302.12 (GND), U303.1 (GND), U303.2 (GND); also elsewhere on the board
unnamed: AE301.1 (A), C304.2
unnamed: C304.1, L301.2
unnamed: D301.2 (A), R301.2
unnamed: J301.5 (CLK), U301.7
unnamed: J301.3 (CMD), U301.9
unnamed: J301.7 (DAT0), U301.6
unnamed: J301.2 (DAT3/CD), U301.10
unnamed: C301.1, J301.11 (SHIELD)
unnamed: R301.1, U302.4 (1PPS)
unnamed: U302.11 (RF_IN), U303.6 (RFOUT)
unnamed: R302.1, U302.3 (RX)
unnamed: R303.1, U302.2 (TX)
unnamed: L301.1, U303.3 (RFIN)

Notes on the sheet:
microSD Card
GNSS

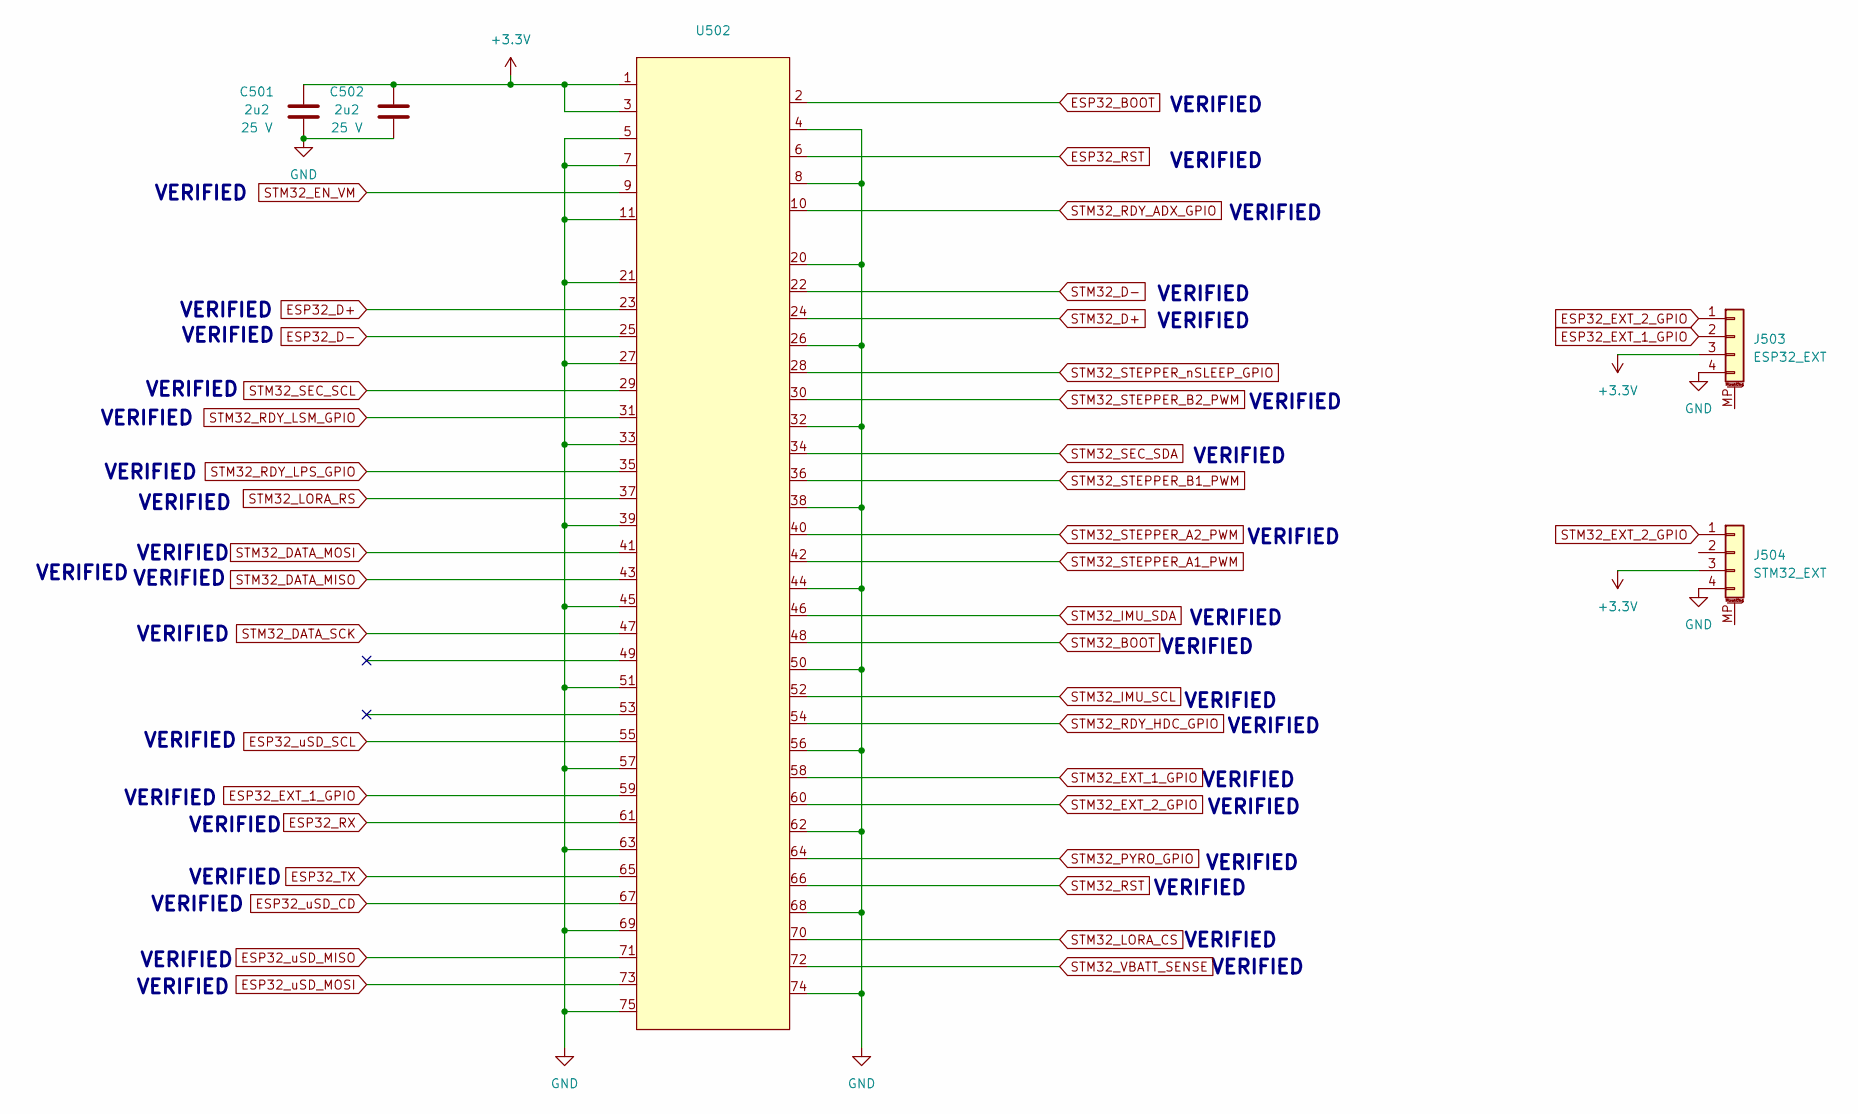
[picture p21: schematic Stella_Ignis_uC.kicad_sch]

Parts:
C501, C502: 2u2; C_0402_1005Metric; Voltage 25 V
J503: ESP32_EXT; Molex_PicoBlade_53261-0471_1x04-1MP_P1.25mm_Horizontal
J504: STM32_EXT; Molex_PicoBlade_53261-0471_1x04-1MP_P1.25mm_Horizontal
U502: TE M.2 Key B

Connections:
+3.3V: C501.2, C502.2, J503.3, J504.3, U502.1, U502.3; also elsewhere on the board
ESP32_BOOT: U502.2; also elsewhere on the board
ESP32_D+: U502.23; also elsewhere on the board
ESP32_D-: U502.25; also elsewhere on the board
ESP32_EXT_1_GPIO: J503.2, U502.59
ESP32_RST: U502.6; also elsewhere on the board
ESP32_RX: U502.61; also elsewhere on the board
ESP32_TX: U502.65; also elsewhere on the board
ESP32_uSD_CD: U502.67; also elsewhere on the board
ESP32_uSD_MISO: U502.71; also elsewhere on the board
ESP32_uSD_MOSI: U502.73; also elsewhere on the board
ESP32_uSD_SCL: U502.55; also elsewhere on the board
GND: C501.1, C502.1, J503.4, J504.4, U502.4, U502.5, U502.7, U502.8, U502.11, U502.20, U502.21, U502.26, U502.27, U502.32, U502.33, U502.38, U502.39, U502.44, U502.45, U502.50, U502.51, U502.56, U502.57, U502.62, U502.63, U502.68, U502.69, U502.74, U502.75; also elsewhere on the board
STM32_BOOT: U502.48; also elsewhere on the board
STM32_D+: U502.24; also elsewhere on the board
STM32_D-: U502.22; also elsewhere on the board
STM32_DATA_MISO: U502.43; also elsewhere on the board
STM32_DATA_MOSI: U502.41; also elsewhere on the board
STM32_DATA_SCK: U502.47; also elsewhere on the board
STM32_EN_VM: U502.9; also elsewhere on the board
STM32_EXT_1_GPIO: U502.58
STM32_EXT_2_GPIO: J504.1, U502.60
STM32_IMU_SCL: U502.52; also elsewhere on the board
STM32_IMU_SDA: U502.46; also elsewhere on the board
STM32_LORA_CS: U502.70; also elsewhere on the board
STM32_LORA_RS: U502.37; also elsewhere on the board
STM32_PYRO_GPIO: U502.64; also elsewhere on the board
STM32_RDY_ADX_GPIO: U502.10; also elsewhere on the board
STM32_RDY_HDC_GPIO: U502.54; also elsewhere on the board
STM32_RDY_LPS_GPIO: U502.35; also elsewhere on the board
STM32_RDY_LSM_GPIO: U502.31; also elsewhere on the board
STM32_RST: U502.66; also elsewhere on the board
STM32_SEC_SCL: U502.29; also elsewhere on the board
STM32_SEC_SDA: U502.34; also elsewhere on the board
STM32_STEPPER_A1_PWM: U502.42; also elsewhere on the board
STM32_STEPPER_A2_PWM: U502.40; also elsewhere on the board
STM32_STEPPER_B1_PWM: U502.36; also elsewhere on the board
STM32_STEPPER_B2_PWM: U502.30; also elsewhere on the board
STM32_STEPPER_nSLEEP_GPIO: U502.28
STM32_VBATT_SENSE: U502.72; also elsewhere on the board

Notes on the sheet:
VERIFIED

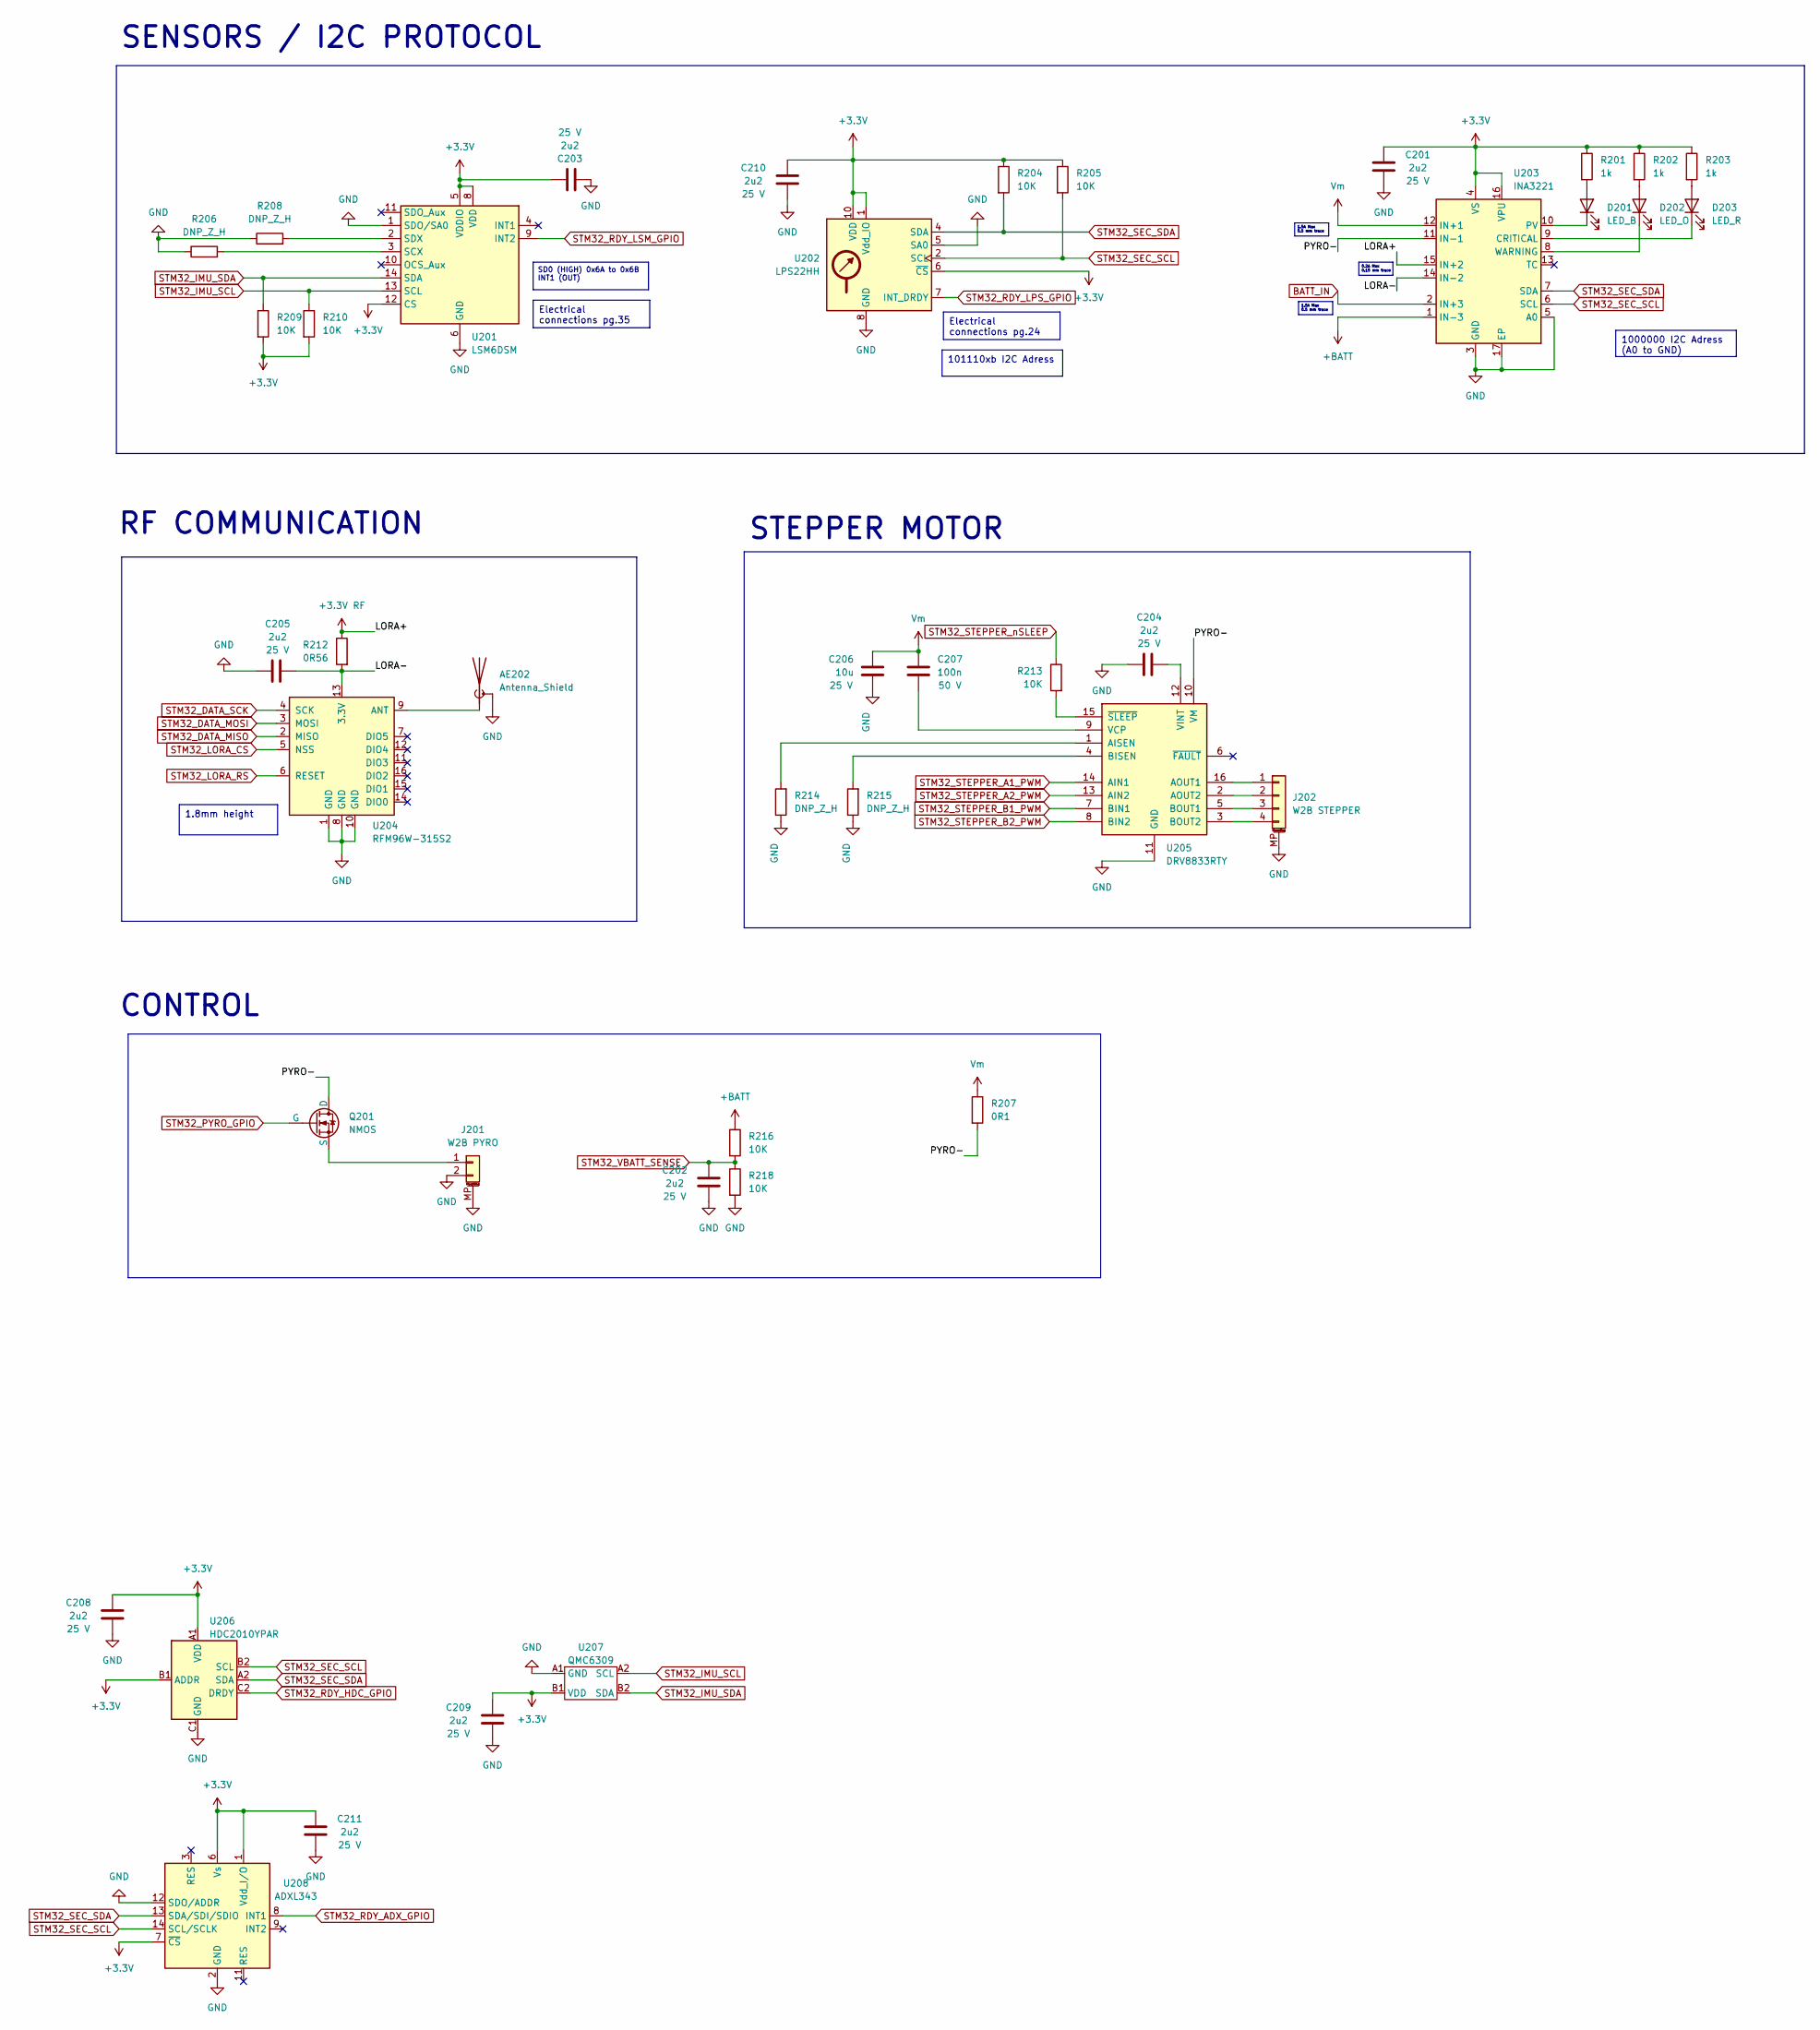
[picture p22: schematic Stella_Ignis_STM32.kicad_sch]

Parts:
AE202: Antenna_Shield; U.FL_Hirose_U.FL-R-SMT-1_Vertical
C201, C202, C203, C204, C205, C208, C209, C210, C211: 2u2; C_0402_1005Metric; Voltage 25 V
C206: 10u; C_0603_1608Metric; Voltage 25 V
C207: 100n; C_0402_1005Metric; Voltage 50 V
D201: LED_B; D_0603_1608Metric
D202: LED_O; D_0603_1608Metric
D203: LED_R; D_0603_1608Metric
J201: W2B PYRO; Molex_PicoBlade_53261-0271_1x02-1MP_P1.25mm_Horizontal
J202: W2B STEPPER; Molex_PicoBlade_53261-0471_1x04-1MP_P1.25mm_Horizontal
Q201: NMOS; SOT-23
R201, R202, R203: 1k; R_0402_1005Metric
R204, R205, R209, R210, R213, R216, R218: 10K; R_0402_1005Metric
R206, R208, R214, R215: DNP_Z_H; R_0402_1005Metric
R207: 0R1; R_0805_2012Metric
R212: 0R56; R_0805_2012Metric
U201: LSM6DSM; LGA-14_3x2.5mm_P0.5mm_LayoutBorder3x4y
U202: LPS22HH; ST_HLGA-10_2x2mm_P0.5mm_LayoutBorder3x2y
U203: INA3221; Texas_RGV0016A_VQFN-16-1EP_4x4mm_P0.65mm_EP2.1x2.1mm
U204: RFM96W-315S2; MODULE_RFM96W-433S2
U205: DRV8833RTY; Texas_RTY_WQFN-16-1EP_4x4mm_P0.65mm_EP2.1x2.1mm
U206: HDC2010YPAR; Texas_DSBGA-6_0.9x1.4mm_Layout2x3_P0.5mm
U207: QMC6309; WLCSP-4-X1-WLB0909-4_0.89x0.89mm_P0.5mm
U208: ADXL343; LGA-14_3x5mm_P0.8mm_LayoutBorder1x6y

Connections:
+3.3V: C201.1, C203.2, C208.1, C209.1, C210.1, C211.1, R201.1, R202.1, R203.1, R204.1, R205.1, R209.2, R210.2, U201.5 (VDDIO), U201.8 (VDD), U201.12 (CS), U202.1 (Vdd_IO), U202.6 (~CS), U202.10 (VDD), U203.4 (VS), U203.16 (VPU), U206.A1 (VDD), U206.B1 (ADDR), U207.B1 (VDD), U208.1 (Vdd_I/O), U208.6 (Vs), U208.7 (~CS); also elsewhere on the board
+3.3V RF: R212.1, U203.15 (IN+2); also elsewhere on the board
+BATT: R216.1, U203.1 (IN-3); also elsewhere on the board
/STM32/LORA-: C205.2, R212.2, U203.14 (IN-2), U204.13 (3.3V)
/STM32/PYRO-: Q201.1 (D), R207.2, U203.11 (IN-1), U205.10 (VM)
BATT_IN: U203.2 (IN+3); also elsewhere on the board
GND: AE202.2 (Shield), C201.2, C202.2, C203.1, C204.1, C205.1, C206.2, C208.2, C209.2, C210.2, C211.2, J201.2, J201.MP (MountPin), J202.MP (MountPin), R206.1, R208.1, R214.1, R215.1, R218.2, U201.1 (SDO/SA0), U201.6 (GND), U201.7 (GND), U202.3 (GND), U202.5 (SA0), U202.8 (GND), U202.9 (GND), U203.3 (GND), U203.5 (A0), U203.17 (EP), U204.1 (GND), U204.8 (GND), U204.10 (GND), U205.11 (GND), U205.17 (GND), U206.C1 (GND), U207.A1 (GND), U208.2 (GND), U208.4 (GND), U208.5 (GND), U208.12 (SDO/ADDR); also elsewhere on the board
unnamed: AE202.1 (A), U204.9 (ANT)
unnamed: D201.2 (A), R201.2
unnamed: D201.1 (K), U203.10 (PV)
unnamed: D202.2 (A), R202.2
unnamed: D202.1 (K), U203.8 (WARNING)
unnamed: D203.2 (A), R203.2
unnamed: D203.1 (K), U203.9 (CRITICAL)
unnamed: J201.1, Q201.3 (S)
unnamed: J202.1, U205.16 (AOUT1)
unnamed: J202.2, U205.2 (AOUT2)
unnamed: J202.3, U205.5 (BOUT1)
unnamed: J202.4, U205.3 (BOUT2)
unnamed: R206.2, U201.3 (SCX)
unnamed: R208.2, U201.2 (SDX)
unnamed: R214.2, U205.1 (AISEN)
unnamed: R215.2, U205.4 (BISEN)
unnamed: C207.2, U205.9 (VCP)
unnamed: C204.2, U205.12 (VINT)
unnamed: R213.2, U205.15 (~SLEEP)
STM32_DATA_MISO: U204.2 (MISO); also elsewhere on the board
STM32_DATA_MOSI: U204.3 (MOSI); also elsewhere on the board
STM32_DATA_SCK: U204.4 (SCK); also elsewhere on the board
STM32_IMU_SCL: R210.1, U201.13 (SCL), U207.A2 (SCL); also elsewhere on the board
STM32_IMU_SDA: R209.1, U201.14 (SDA), U207.B2 (SDA); also elsewhere on the board
STM32_LORA_CS: U204.5 (NSS); also elsewhere on the board
STM32_LORA_RS: U204.6 (RESET); also elsewhere on the board
STM32_PYRO_GPIO: Q201.2 (G); also elsewhere on the board
STM32_RDY_ADX_GPIO: U208.8 (INT1); also elsewhere on the board
STM32_RDY_HDC_GPIO: U206.C2 (DRDY); also elsewhere on the board
STM32_RDY_LPS_GPIO: U202.7 (INT_DRDY); also elsewhere on the board
STM32_RDY_LSM_GPIO: U201.9 (INT2); also elsewhere on the board
STM32_SEC_SCL: R205.2, U202.2 (SCL), U203.6 (SCL), U206.B2 (SCL), U208.14 (SCL/SCLK); also elsewhere on the board
STM32_SEC_SDA: R204.2, U202.4 (SDA), U203.7 (SDA), U206.A2 (SDA), U208.13 (SDA/SDI/SDIO); also elsewhere on the board
STM32_STEPPER_A1_PWM: U205.14 (AIN1); also elsewhere on the board
STM32_STEPPER_A2_PWM: U205.13 (AIN2); also elsewhere on the board
STM32_STEPPER_B1_PWM: U205.7 (BIN1); also elsewhere on the board
STM32_STEPPER_B2_PWM: U205.8 (BIN2); also elsewhere on the board
STM32_STEPPER_nSLEEP: R213.1
STM32_VBATT_SENSE: C202.1, R216.2, R218.1; also elsewhere on the board
Vm: C206.1, C207.1, R207.1, U203.12 (IN+1); also elsewhere on the board

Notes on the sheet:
SD0 (HIGH) 0x6A to 0x6B INT1 (OUT)
Electrical connections pg.35
1.5A Max 0.5 mm trace
101110xb I2C Adress
1.8mm height
1000000 I2C Adress (A0 to GND)
Electrical connections pg.24
0.2A Max 0.15 mm trace
STEPPER MOTOR
CONTROL
SENSORS / I2C PROTOCOL
RF COMMUNICATION

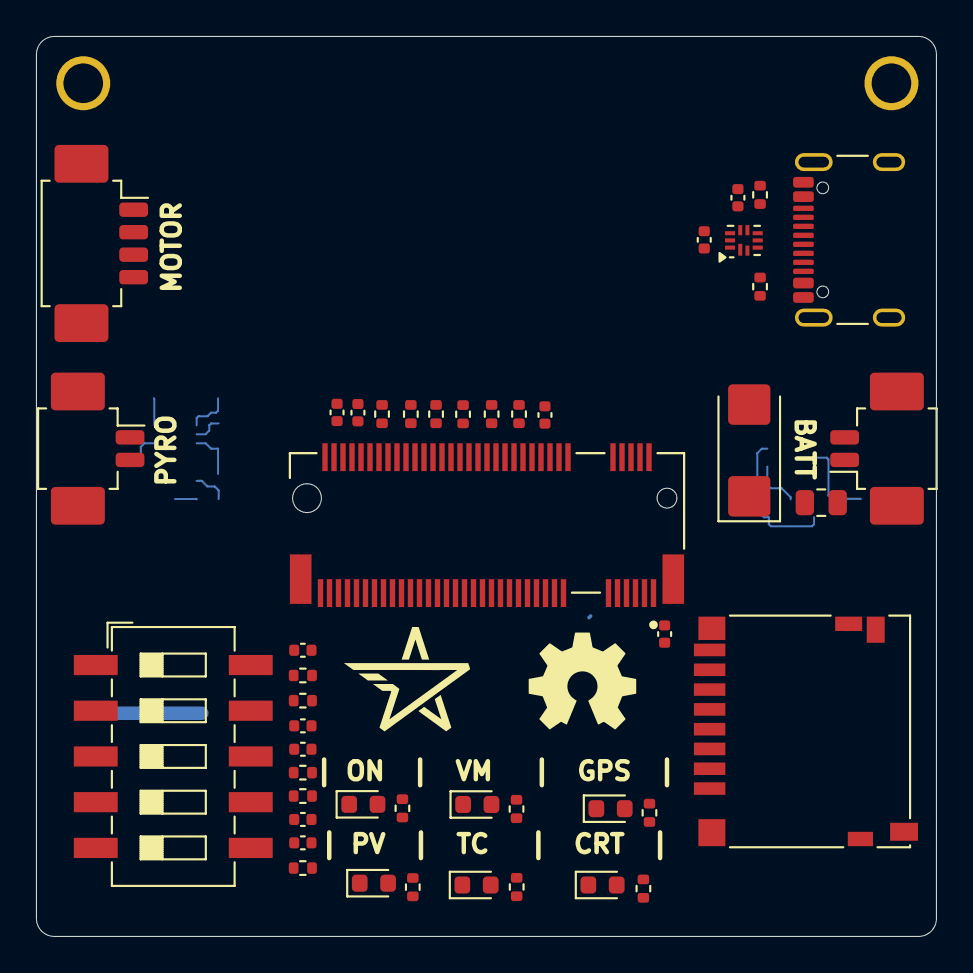
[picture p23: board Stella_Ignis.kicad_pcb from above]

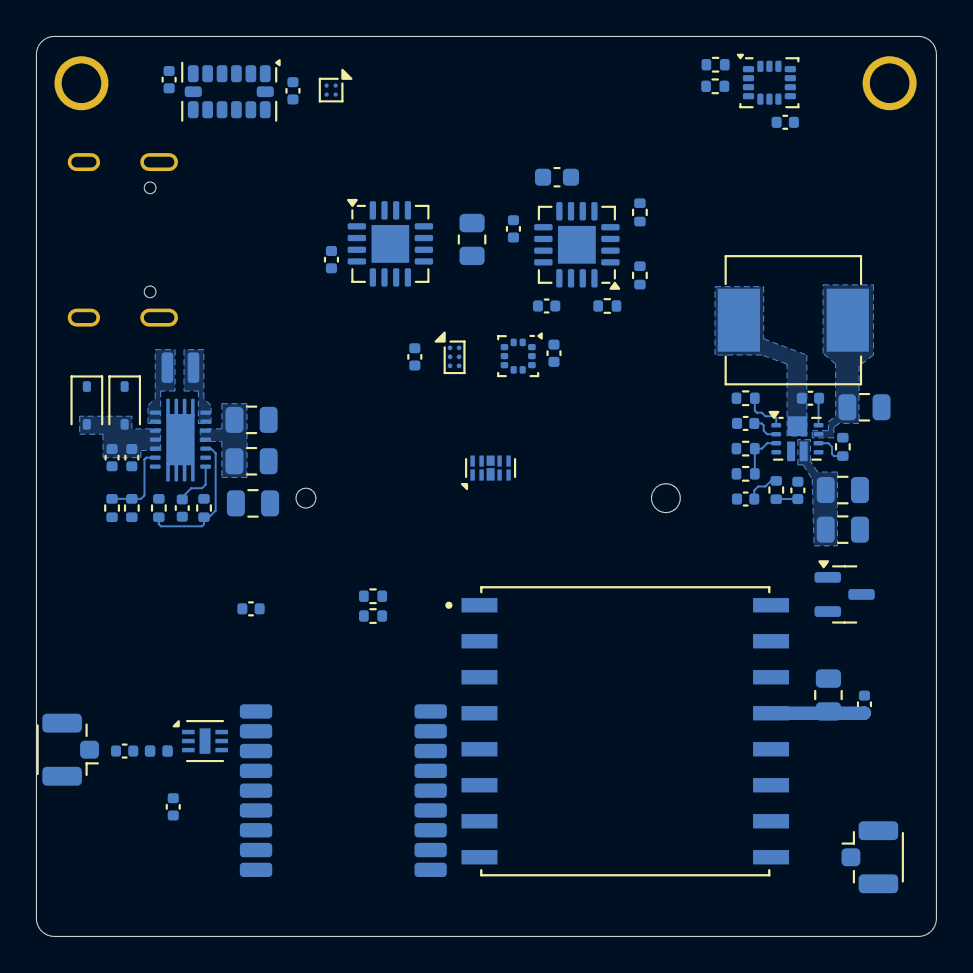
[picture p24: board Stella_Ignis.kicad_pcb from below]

Board: 8 copper layers, 50.0 x 50.0 mm, 113 parts (65 on the bottom side), 97 nets.
